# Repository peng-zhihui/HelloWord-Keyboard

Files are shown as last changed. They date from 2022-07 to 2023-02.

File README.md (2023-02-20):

# 【瀚文】HelloWord-Smart Keyboard

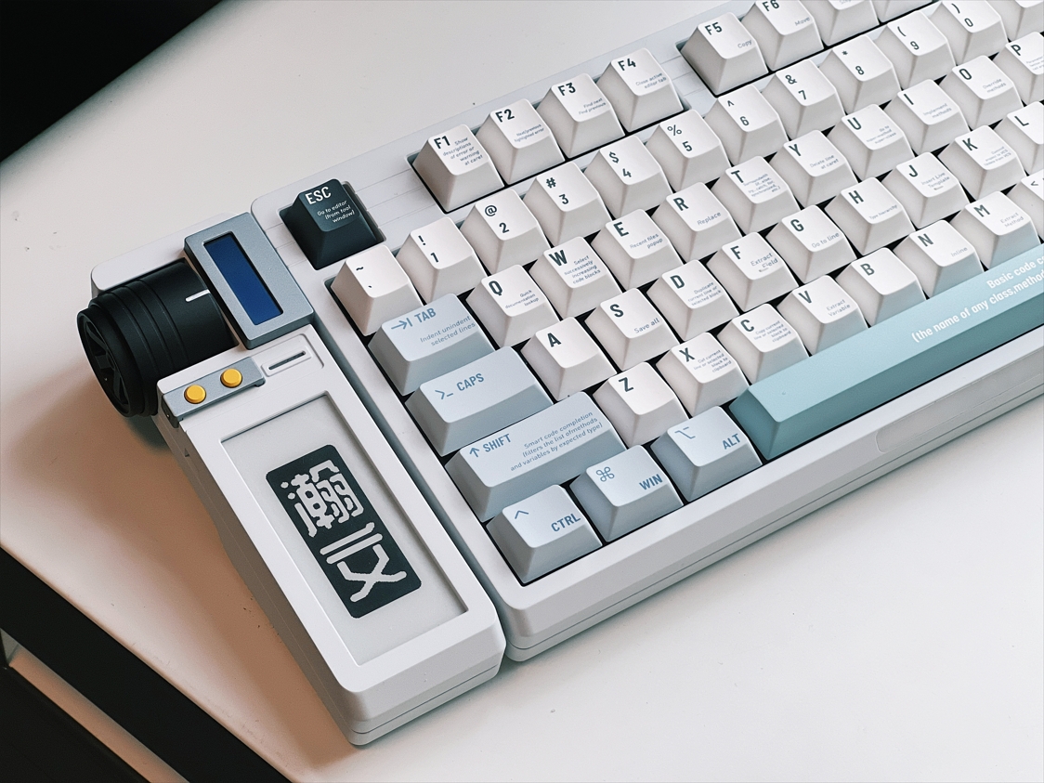
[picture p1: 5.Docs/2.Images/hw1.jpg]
hw1


> `瀚文` 智能键盘是一把我为自己使用需求设计的 **多功能**、**模块化** 机械键盘。
>
> 键盘使用模块化设计，左侧的**多功能场景交互模块**可以替换成各种自定义组件，默认使用的是一个带电子墨水屏以及FOC力反馈旋钮的`Dynamic组件`；键盘使用我自己开发的基于ARM Cortex-M芯片的键盘固件以及模块固件；键盘本体使用移位寄存器方式实现优化的按键扫描电路；模块以及键盘本体可以单独使用，也可以通过串口协议进行相互通信和调用。
>
> **本仓库开源的资料内容包括：**
>
> * 瀚文本体硬件设计的10块PCB设计源文件，提供立创EDA专业版的文件格式
> * 外壳设计结构文件
> * 键盘本体的固件源码（已相对完善）
> * Dynamic组件的固件源码（已完成框架，更多APP扩展WIP）
> * 键盘二次开发SDK（开发中）
>
> **键盘功能演示可以参考：**
>
> * [【自制】我做了一把 模 块 化 机 械 键 盘 !【软核】_哔哩哔哩_bilibili](https://www.bilibili.com/video/BV19V4y1J7Hx)
>
> * [I Made A Customized Modular Keyboard ! - YouTube](https://www.youtube.com/watch?v=mGShD9ZER1c)

**注意：Issues里面是讨论项目开发相关话题的，不要在里面发无意义的消息，不然watch了仓库的人都会收到通知邮件会给别人造成困扰的！！！灌水可以在仓库的Discuss里讨论！**

---

## 1. 项目说明

### 1.0 更新说明：
**23.2.20更新**
* 修改`CUSTOM_HID_EPOUT_ADDR = 2`，HID_RxCpltCallback位置变更到CUSTOM_HID_OutEvent_FS中（原来的位置可能导致while循环内无法发送report）。

  > * main里面增加了RGB控制相关代码，可以通过HID协议发送数据包来控制键盘RGB效果
  > * 已对接SignalRGB，Software中添加SignalRGB插件
  > * report包大小33字节，前三个字节依次为reportid(本项目为2)、控制命令（0xAC（上位机控制），0xBD（关闭上位机控制），report包次序（一个包最多传10个RGB值，需要多个包拼接，从0计算）；后30字节为RGB值。

**22.8.31更新：**

* 添加`Test-Dynamic-fw.bin`测试固件，烧录到模块之后可以体验各种不同力反馈的滚轮效果。

  > * 注意测试版固件会在每次上电之后校准电机，如果校准失败需要重新上电（未来正式使用的时候校准只需要一次就行了）;
  > * 模块上两个按钮可以切换不同模式;
  > * 硬件上有一个地方需要注意的地方是模块的fpc线一定要选短一点的，不然电阻太大会影响压降，同时需要先自己确认一下编码器是正常工作的（可以用Debug查看编码器数据）。

**22.8.22更新：**

* 添加STEP格式的3D模型文件，全套包括定位板的模型都发出来了.

**22.8.20更新：**

* PCB工程更新，见仓库的工程链接，所有元器件能在立创直接下单的都改成了对应的封装，方便大家配置BOM.

**22.8.13更新：**

* 新打样的PCB已经收到，但是由于何同学这周发视频，为了避免带来不必要的压力，所以决定错峰下周六再把PCB工程更新（doge）.

**22.7.31更新：**

* 添加键盘硬件所有设计原理图文件（电路还有些bug没修复，如视频里的飞线，会晚些等新版PCB打样收到验证没问题后更新）
* 添加键盘固件源代码
* 添加Dynamic组件源代码

### 1.1 项目文件说明：

#### 1.1.1 Hardware

Hardware文件夹内是瀚文键盘里面用到的所有电路的原理图和PCB文件，目前提供的是[立创EDA专业版](https://oshwhub.com/pengzhihui/b11afae464c54a3e8d0f77e1f92dc7b7)格式的源文件以及Gerber格式的光绘文件用于提供给厂家进行直接加工。

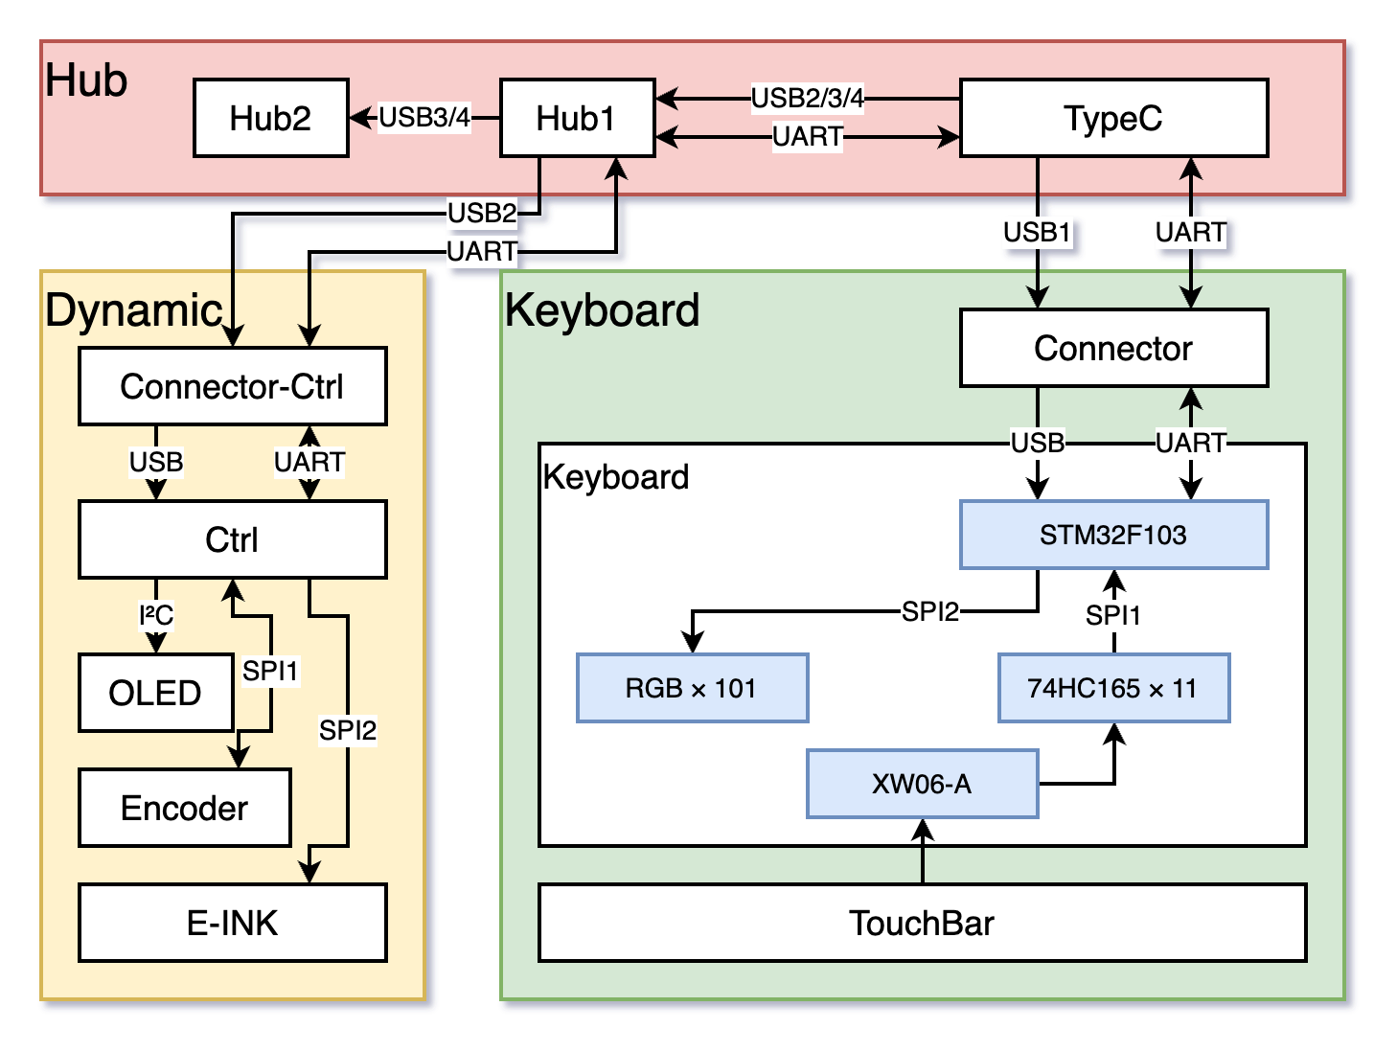
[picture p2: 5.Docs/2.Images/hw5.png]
hw0


一共有如下几块板子：

- **HelloWord-Keyboard**：主键盘的PCB，控制器为STM32F103，可以配合底座单独使用，提供常规按键输入功能，带全按键独立RGB灯。
- **HelloWord-Ctrl**：左侧Dynamic组件的PCB，控制器为STM32F405，可以配合底座单独使用，提供FOC力反馈旋钮、电子墨水屏显示、OLED显示、RGB灯等功能。
- **HelloWord-Connector**：主键盘用于连接底座的触点PCB，通过FFC排线与键盘PCB连接。
- **HelloWord-Connector-Ctrl**：Dynamic组件用于连接底座的触点PCB，通过FFC排线与Dynamic组件PCB连接。
- **HelloWord-Encoder**：磁编码器PCB，用于对无刷电机进行位置反馈，需要配合一个径向充磁的永磁铁工作。
- **HelloWord-Hub1**：底座上扩展出的两个额外USB-A接口转接PCB，通过FFC排线和TypeC接口板连接。
- **HelloWord-Hub2**：底座上扩展出的两个额外USB-A接口的母座PCB，预留的是USB3.0母座和引脚，但是目前只使用到了2.0接口，未来可以升级到USB3.0的HUB。
- **HelloWord-TypeC**：底座上用于连接电脑的TypeC接口PCB，板载了电源充电管理芯片，以及USB-HUB芯片，通过FFC排线连接其余模块。
- **HelloWord-OLED**：Dynamic组件上OLED屏幕的最小驱动电路以及转接板。
- **HelloWord-TouchBar**：可选的电容触摸条模块PCB，使用6按键电容触摸芯片组成一个线性感应阵列，通过FFC排线和主键盘PCB连接。

#### 1.1.2 Firmware

Firmware中提供了上面所有板子的固件源码，以及**预编译好的bin固件**可以直接烧录，主要包含以下两个工程：

* **HelloWord-Keyboard-fw**：主键盘的固件，主要实现了基于硬件SPI和移位寄存器的高速按键扫描、基于硬件SPI&DMA的总线式RGB灯控制、HID高速设备键盘枚举&报文协议实现、非易失存储配置、多层按键映射等功能。
* **HelloWord-Dynamic-fw：**Dynamic组件的固件，主要实现了基于FOC的电机控制代码、可配置触感封装类、电子墨水屏驱动、OLED驱动、USB全速复合设备枚举和通信协议、RGB灯控制等功能。

工程都是基于STM32HAL实现的，所以提供了对应的`.ioc`文件，可以自行用STM32CubeMX打开，生成对应的keil或者STM32IDE工程文件。当让也可以像我一样，用CLion或者STM32CubeIDE进行编译和下载。

`_Release`文件夹里是预编译好的bin文件，可以用**ST-Link Utillity**或者STM32CubeProgrammer之类的软件直接下载到芯片。

关于固件的实现细节后文有讲解。

> 把CLion变成STM32的IDE的方法参考我之前发的一篇教程：[配置CLion用于STM32开发【优雅の嵌入式开发】](https://zhuanlan.zhihu.com/p/145801160) 。

#### 1.1.3 Software

Software中提供了一些用于和键盘交互的电脑端上位机软件，包括视频里演示的傻瓜化修改墨水屏图片的上位机软件，以及后续会逐步补充用于**修改键位的图形化软件**给**模块添加APP**的应用商店软件，这些还在开发中。

#### 1.1.4 Tools

Tools主要是提供一些三方的工具软件，比如**STM32 ST-LINK Utility** 、用于安装驱动的**zadig**等等。

#### 1.1.5 3D Model

文件夹里是键盘用到的所有结构件的3D模型文件，可以用于3D打印。

#### 1.1.6 Docs

相关的参考文件，包括芯片的Datasheet等。

## 2. 硬件架构说明

**关于结构设计？**

瀚文的结构包括三大部分：**扩展坞底座**、**键盘输入模块**和**可替换的多功能交互模块**，键盘输入模块和可替换的多功能交互模块通过若干接触式触点连接在所述扩展坞底座顶部：

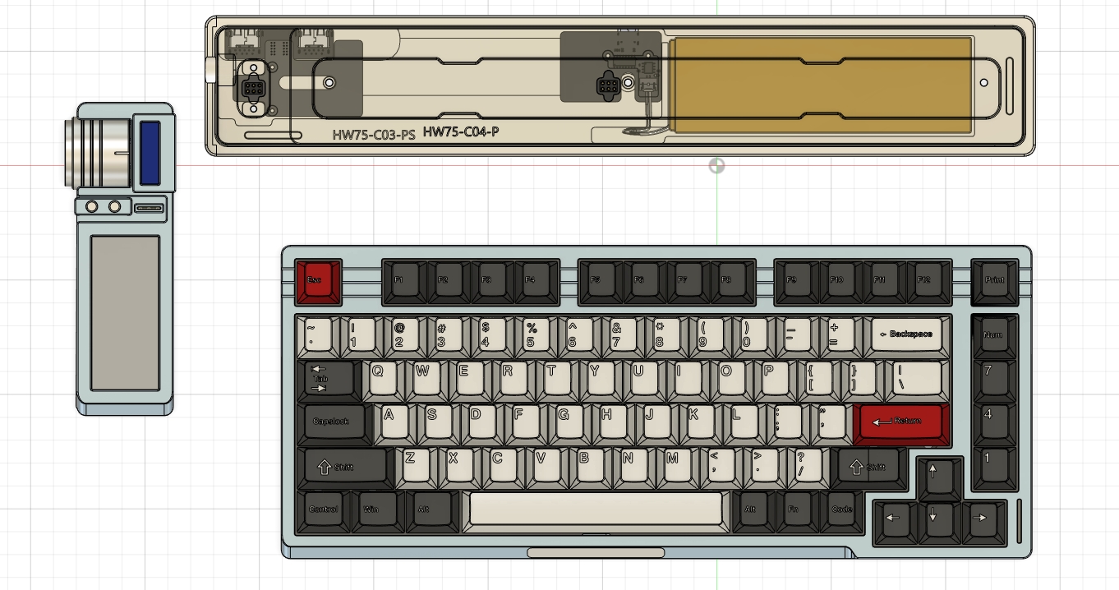
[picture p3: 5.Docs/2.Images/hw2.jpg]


而键盘本体也是一个标准的客制化键盘层叠结构设计，包含减震棉、PCBA、定位板、轴下垫等：

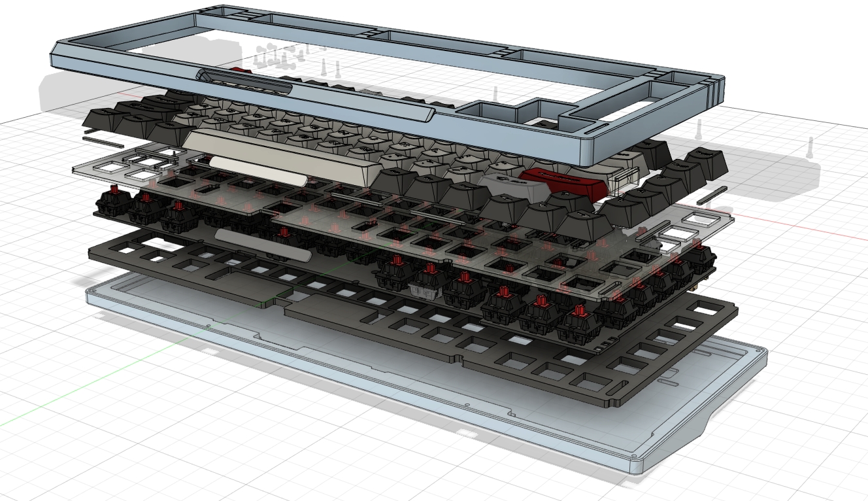
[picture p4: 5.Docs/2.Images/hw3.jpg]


键盘的结构设计主要是Xikii根据S98修改而来，为75键布局，有其他布局需要的同学可以自行修改PCB和固件适配。

> 关于视频中展示的结构件，由于是Xikii的方案所以我也不好擅自把源文件放出，而且原始版本结构是用于CNC机加工的，成本会比较高。
>
> 所以我也让Xikii帮忙设计一套简化版可用于3D的结构件，并开源出来放到仓库。

**关于芯片选型？**

- 键盘主控选用的芯片是STM32F103CBT6，实际上C8T6也可以，不过考虑到未来固件功能的扩展性，Flash大一倍的CBT6性价比更高。这块由于我固件基本都是使用HAL库实现的，因此实际上也可以把主控替换成STM32系列的任何一款芯片，需要支芯片有2个SPI硬件接口分别用于按键扫描以及RGB灯驱动，以及一个全速USB接口即可。
- Dynamic组件主控的STM32F4，这个是因为我手边这款芯片比较多，理论上可以替换为性价比更高的F1系列的，只要芯片具备一个高级定时器用于PWM生成、2个硬件SPI接口用于编码器和电子墨水屏通信、一个I2C接口用于OLED驱动，以及一个全速USB接口即可。
- 电机的磁编码器芯片我是使用AS5047P，也是一款很常用性能很好的磁编码芯片，不过成本略高，我只是因为手边有所以选了这款，也是可以修改为其他更便宜的型号的比如MT6816等，当然也需要修改固件驱动代码。
- 按键扫描用的移位寄存器使用的74HC165，国产芯片零售的话大概0.5元一片，一片可以驱动8个按键，按照你自己需要的按键数目修改串联的寄存器芯片即可。进口的165比如TI原装的要比国产贵一些，性能也会稍微好点，不过由于本项目中按键扫描频率4MHz已经完全够用了，因此哪怕国产的16MHz芯片也绰绰有余了。
- 电容触摸板使用的是一个6通道电容触摸按键芯片XW06A实现的，这个对于PCB感应盘的设计有一定要求，仓库已经提供了设计好的PCB。对于该芯片的读取方式，其实和普通按键没有区别，所以本方案中也是使用74HC165进行扫描读取的。
- 电机FOC驱动电路完全是从我的Ctrl驱动器中移植过来的，使用FD8288Q作为栅极驱动器，无需电流传感器。

**关于烧录方式？**

使用JLink、STLink之类的调试器烧录，我在PCB和外壳上都预留了SWD调试口。对于没有硬件开发经验的同学，我晚点也会放出一个Bootloader，可以直接通过USB口进行固件升级。

**关于电机选型？**

我使用的是一个2204的二手电机，不过这一款电机目前好像不太好买，大家可以选取类似尺寸的无刷电机替换，参数方面需要KV值低一些，最好200左右。电机需要手动在转子上安装一个径向充磁的永磁体用于编码器定位，不同型号的电机需要对FOC参数进行一些调整。

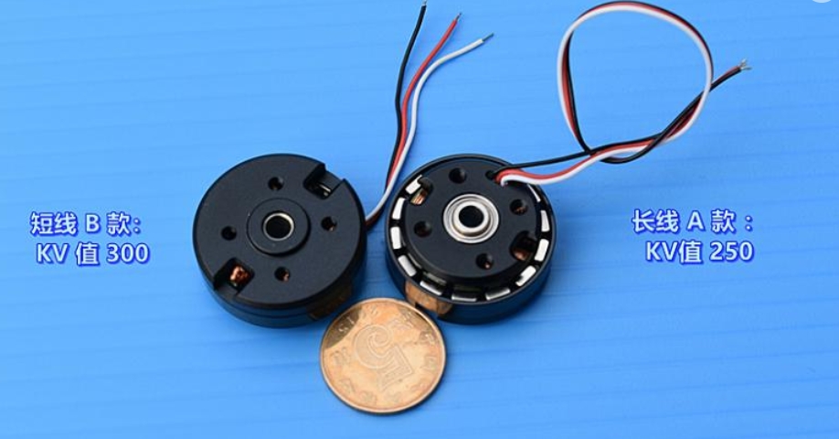
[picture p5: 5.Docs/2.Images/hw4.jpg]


## 3. 软件架构说明

**关于键盘固件的按键映射方式？**

为了充分发挥视频中提到的移位寄存器扫描方案的优势，固件代码中将PCB Layout走线和按键扫描顺序解耦，通过软件进行重映射。也就是说PCB中按键的连接可以是任意的，走完线之后可以在`hw_keyboard.h`文件中的`keyMap[KEYMAP_NUM][IO_NUMBER]`中指定映射方式。

> 这是一个二维数组，代表有`KEYMAP_NUM`层键位映射，每一层有`IO_NUMBER`个按键（也就是你的键盘按键数目）；其中第0层是特殊的，负责映射PCB按键的随机布局到键盘标准按键布局，后续的1、2、3、4...层都是自定义的，负责映射标准按键布局到任意布局。

**举个例子：**

考虑原理图中箭头指的那个按键，这个按键可以在PCB的任意位置，但是我们可以看到，它是从左到右（按74HC165的连接顺序，也即移位扫描顺序）的第10颗，因此它的编号为9（从0开始算）.

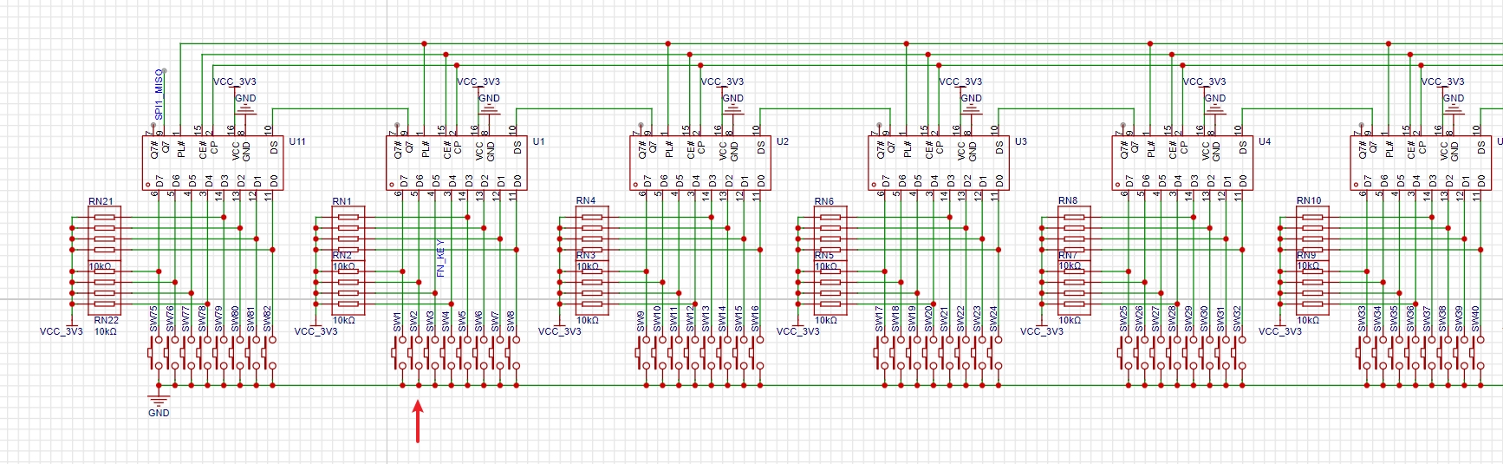
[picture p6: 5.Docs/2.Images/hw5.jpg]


如果我们在实际的PCB板上把它放在了**右边Alt**的位置，那么参考在下图代码**红色框**中的第1层映射（也就是标准布局）中的`RIGHT_ALT`的序号是76，那么在第0层映射的76号变量就填入9（蓝色框）.

这样依次把你PCB上所有按键都填入0层映射，就得到了一个映射好的标准键盘了。后续2、3、4、5...层需要怎么映射就随意修改添加即可，也不需要再使用数字编号，而是可以直接用枚举的按键名称很方便。

> 所以对于想修改键盘配列的人，只需要再原理图上添加或删减几个串联的74HC165，然后PCB随意走线，再将代码中0层映射删减或增加一些数字即可（比如在下面的例子中我的键盘是83键的）；后面几层的修改就以此类推了。

代码中通过`keyboard.Remap`函数来映射不同层，比如`keyboard.Remap(2)`这一句是使用第2层映射。

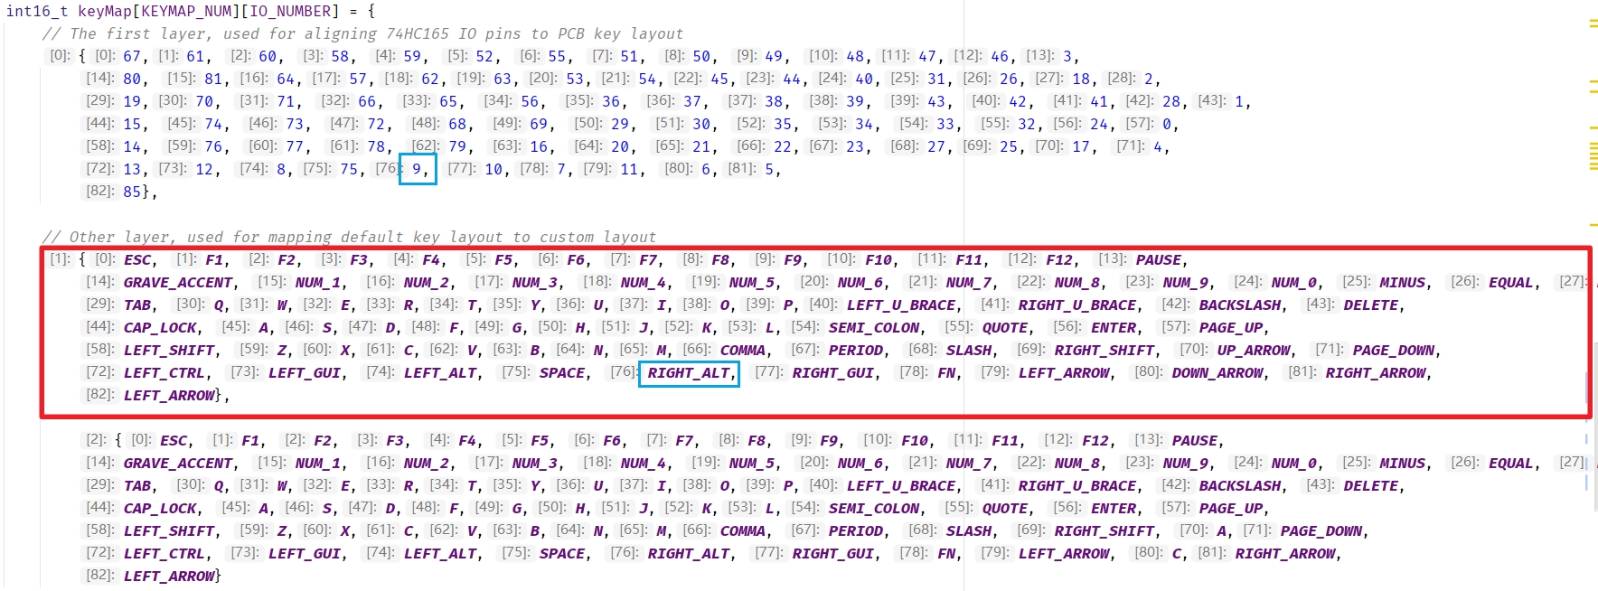
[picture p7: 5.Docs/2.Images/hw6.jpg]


**关于键盘固件的滤波方法？**

固件中使用了每个按键独立的滤波，但是是以一种非常高效的方式来实现的（毕竟1KHz的报文，每个报文期间至少扫描两次按键，意味着每秒钟需要进行 **1000\*2\*[按键数目]** 次数的滤波）。

基本原理很简单，就是按键抖动的原因是按下后会在高低电平之间反复横跳，这个稳定时间一般是几十us（注意是电平稳定时间，不是按键触发时间，后者是由于按键簧片接触时间的不确定性导致的，可能长达数ms）。

在QMK的[qmk_firmware/feature_debounce_type](https://github.com/qmk/qmk_firmware/blob/master/docs/feature_debounce_type.md)文档中描述了其使用的几种滤波方法，分为Eager和Defer、对称和非对称等，

默认是使用**对称延迟全局滤波**，也就是说是对所有按键进行同等的滤波，等所有的按键都稳定了不再变化，再提交扫描数据。

> 与之对应的是激进滤波方法，也就是说一旦检测到按键变化就提交数据，但是在这之后的N毫秒时间内不再响应任何按键（也就避免了把不断抖动的按键提交上去）。这种方法触发延迟低，但是对噪声很敏感，容易误触发。

我在瀚文的固件中使用的是**对称延迟独立滤波**，也就是对每个按键进行两次检测，如果第一次检测到了按键变化，那么相隔N微秒（这个参数可以配置，大于按键典型抖动时间即可）再检测一次，如果两次检测结果一致，那么判断按键被按下，此时可以确保按键发生了变化，且不会重复触发按键，兼顾延迟和稳定性。

这个过程是通过异或运算进行高效处理的，正好按键buffer由于是移位寄存器扫描得到的，本身就是每一位代表一个按键，所以滤波效率非常高，实测效果也挺好的。

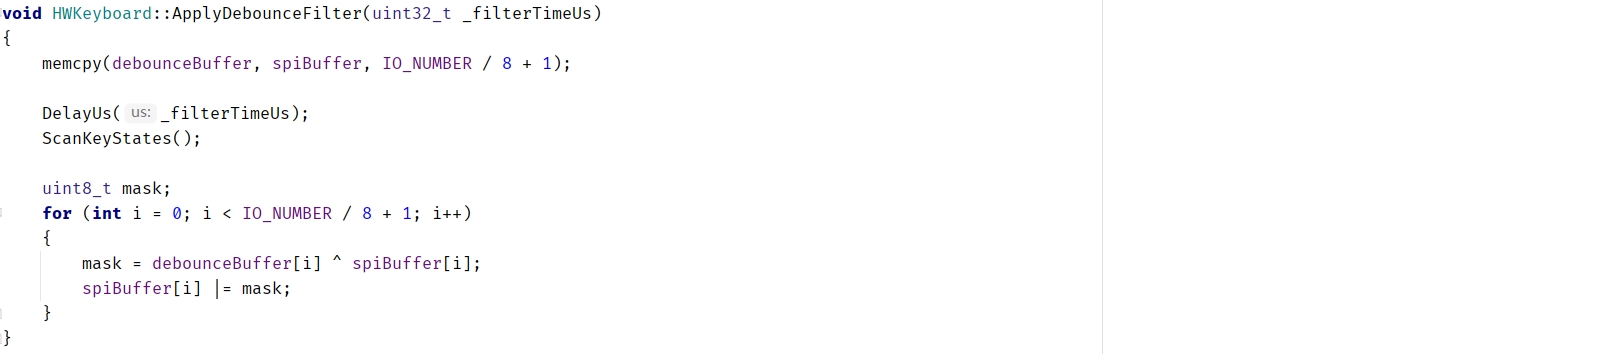
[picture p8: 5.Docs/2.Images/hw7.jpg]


**关于键盘固件的HID描述符？**

这个可以直接参考源码的`usbd_customhid.c`文件，我配置了两个ReportID，ID-0是上报键位扫描数据的（全键无冲），ID-1是预留用于后续跟上位机改键软件通信用的。

**关于RGB的控制？**

代码中使用的是单总线的ws2812b系列灯珠，一根线就可以串联一大堆RGB，而且代码中实现了SPI-DMA模拟时序，得到了超高的刷新率。

目前代码里只写了一个demo灯效（非常简单就是轮询色彩），自己添加额外的灯效的话，通过`keyboard.SetRgbBuffer`函数设置RGB值，然后`SyncLights`把数据发送给LED即可：

```
while (true)
    {
        /*---- This is a demo RGB effect ----*/
        static uint32_t t = 1;
        static bool fadeDir = true;

        fadeDir ? t++ : t--;
        if (t > 250) fadeDir = false;
        else if (t < 1) fadeDir = true;

        for (uint8_t i = 0; i < HWKeyboard::LED_NUMBER; i++)
            keyboard.SetRgbBuffer(i, HWKeyboard::Color_t{(uint8_t) t, 50, 0});
        /*-----------------------------------*/

        // Send RGB buffers to LEDs
        keyboard.SyncLights();
    }
```

## 4. SDK设计 & 二次开发

待补充。

> 感谢以下项目：
>
> [Lexikos/AutoHotkey_L: AutoHotkey - macro-creation and automation-oriented scripting utility for Windows. (github.com)](https://github.com/Lexikos/AutoHotkey_L)
>
> [olikraus/u8g2: U8glib library for monochrome displays, version 2 (github.com)](https://github.com/olikraus/u8g2)
>
> [simplefoc/Arduino FOC for BLDC  (github.com)](https://github.com/simplefoc/Arduino-FOC)
>
> [zhongyang219/TrafficMonitor: 这是一个用于显示当前网速、CPU及内存利用率的桌面悬浮窗软件，并支持任务栏显示，支持更换皮肤。 (github.com)](https://github.com/zhongyang219/TrafficMonitor)

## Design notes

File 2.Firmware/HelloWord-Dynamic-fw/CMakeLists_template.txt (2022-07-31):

#THIS FILE IS AUTO GENERATED FROM THE TEMPLATE! DO NOT CHANGE!
set(CMAKE_SYSTEM_NAME Generic)
set(CMAKE_SYSTEM_VERSION 1)
cmake_minimum_required(VERSION 3.19)

# specify cross compilers and tools
set(CMAKE_C_COMPILER arm-none-eabi-gcc)
set(CMAKE_CXX_COMPILER arm-none-eabi-g++)
set(CMAKE_ASM_COMPILER arm-none-eabi-gcc)
set(CMAKE_AR arm-none-eabi-ar)
set(CMAKE_OBJCOPY arm-none-eabi-objcopy)
set(CMAKE_OBJDUMP arm-none-eabi-objdump)
set(SIZE arm-none-eabi-size)
set(CMAKE_TRY_COMPILE_TARGET_TYPE STATIC_LIBRARY)

# project settings
project(HelloWord-Dynamic-fw C CXX ASM)
set(CMAKE_CXX_STANDARD 17)
set(CMAKE_C_STANDARD 11)

# for use printf & scanf with float
set(COMMON_FLAGS "-specs=nosys.specs -specs=nano.specs -u _printf_float -u _scanf_float")

#Uncomment for hardware floating point
add_compile_definitions(ARM_MATH_CM4;ARM_MATH_MATRIX_CHECK;ARM_MATH_ROUNDING)
add_compile_options(-mfloat-abi=hard -mfpu=fpv4-sp-d16)
add_link_options(-mfloat-abi=hard -mfpu=fpv4-sp-d16)

#Uncomment for software floating point
#add_compile_options(-mfloat-abi=soft)

add_compile_options(-mcpu=cortex-m4 -mthumb -mthumb-interwork)
add_compile_options(-ffunction-sections -fdata-sections -fno-common -fmessage-length=0)
set(CMAKE_CXX_FLAGS "${CMAKE_CXX_FLAGS} -fno-exceptions -fno-rtti")

# uncomment to mitigate c++17 absolute addresses warnings
#set(CMAKE_CXX_FLAGS "${CMAKE_CXX_FLAGS} -Wno-register")

if ("${CMAKE_BUILD_TYPE}" STREQUAL "Release")
    message(STATUS "Maximum optimization for speed")
    add_compile_options(-Ofast)
elseif ("${CMAKE_BUILD_TYPE}" STREQUAL "RelWithDebInfo")
    message(STATUS "Maximum optimization for speed, debug info included")
    add_compile_options(-Ofast -g)
elseif ("${CMAKE_BUILD_TYPE}" STREQUAL "MinSizeRel")
    message(STATUS "Maximum optimization for size")
    add_compile_options(-Os)
else ()
    message(STATUS "Minimal optimization, debug info included")
    add_compile_options(-Og -g)
endif ()

include_directories(
        ./
        Core/Inc
        Drivers/STM32F4xx_HAL_Driver/Inc
        Drivers/STM32F4xx_HAL_Driver/Inc/Legacy
        Drivers/CMSIS/Device/ST/STM32F4xx/Include
        Drivers/CMSIS/Include
        Middlewares/Third_Party/FreeRTOS/Source/include
        Middlewares/Third_Party/FreeRTOS/Source/CMSIS_RTOS_V2
        Middlewares/Third_Party/FreeRTOS/Source/portable/GCC/ARM_CM4F
        Middlewares/ST/STM32_USB_Device_Library/Core/Inc
        Middlewares/ST/STM32_USB_Device_Library/Class/CDC/Inc
        USB_DEVICE/App
        USB_DEVICE/Target
        BSP/fibre/cpp/include
        BSP/u8g2
        BSP/u8g2/cpp
        BSP/uvector
        BSP/eink
        Platform/Utils
        UserApp
)

add_definitions(-DUSE_HAL_DRIVER -DSTM32F4 -DSTM32F4xx -DSTM32F405xx -DconfigAPPLICATION_ALLOCATED_HEAP)

file(GLOB_RECURSE SOURCES
        "startup/*.*"
        "Drivers/*.*"
        "Core/*.*"
        "BSP/*.*"
        "Middlewares/*.*"
        "USB_DEVICE/*.*"
        "Ctrl/*.*"
        "Platform/*.*"
        "UserApp/*.*"
        )

set(LINKER_SCRIPT ${CMAKE_SOURCE_DIR}/STM32F405RGTx_FLASH.ld)

add_link_options(-Wl,-gc-sections,--print-memory-usage,-Map=${PROJECT_BINARY_DIR}/${PROJECT_NAME}.map)
add_link_options(-mcpu=cortex-m4 -mthumb -mthumb-interwork)
add_link_options(-T ${LINKER_SCRIPT})

link_directories("Drivers/CMSIS/Lib")
link_libraries("arm_cortexM4lf_math.a")

add_executable(${PROJECT_NAME}.elf ${SOURCES} ${LINKER_SCRIPT})

set(HEX_FILE ${PROJECT_BINARY_DIR}/${PROJECT_NAME}.hex)
set(BIN_FILE ${PROJECT_BINARY_DIR}/${PROJECT_NAME}.bin)

add_custom_command(TARGET ${PROJECT_NAME}.elf POST_BUILD
        COMMAND ${CMAKE_OBJCOPY} -Oihex $<TARGET_FILE:${PROJECT_NAME}.elf> ${HEX_FILE}
        COMMAND ${CMAKE_OBJCOPY} -Obinary $<TARGET_FILE:${PROJECT_NAME}.elf> ${BIN_FILE}
        COMMENT "Building ${HEX_FILE}
Building ${BIN_FILE}")

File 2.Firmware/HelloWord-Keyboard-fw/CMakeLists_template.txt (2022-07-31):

#THIS FILE IS AUTO GENERATED FROM THE TEMPLATE! DO NOT CHANGE!
set(CMAKE_SYSTEM_NAME Generic)
set(CMAKE_SYSTEM_VERSION 1)
cmake_minimum_required(VERSION 3.22)

# specify cross-compilers and tools
set(CMAKE_C_COMPILER arm-none-eabi-gcc)
set(CMAKE_CXX_COMPILER arm-none-eabi-g++)
set(CMAKE_ASM_COMPILER  arm-none-eabi-gcc)
set(CMAKE_AR arm-none-eabi-ar)
set(CMAKE_OBJCOPY arm-none-eabi-objcopy)
set(CMAKE_OBJDUMP arm-none-eabi-objdump)
set(SIZE arm-none-eabi-size)
set(CMAKE_TRY_COMPILE_TARGET_TYPE STATIC_LIBRARY)

# project settings
project(HelloWord-Keyboard-fw C CXX ASM)
set(CMAKE_CXX_STANDARD 17)
set(CMAKE_C_STANDARD 11)
set(CMAKE_CXX_FLAGS "${CMAKE_CXX_FLAGS} -fno-exceptions -fno-rtti")

#Uncomment for hardware floating point
#add_compile_definitions(ARM_MATH_CM4;ARM_MATH_MATRIX_CHECK;ARM_MATH_ROUNDING)
#add_compile_options(-mfloat-abi=hard -mfpu=fpv4-sp-d16)
#add_link_options(-mfloat-abi=hard -mfpu=fpv4-sp-d16)

#Uncomment for software floating point
#add_compile_options(-mfloat-abi=soft)

add_compile_options(-mcpu=cortex-m3 -mthumb -mthumb-interwork)
add_compile_options(-ffunction-sections -fdata-sections -fno-common -fmessage-length=0)

# uncomment to mitigate c++17 absolute addresses warnings
#set(CMAKE_CXX_FLAGS "${CMAKE_CXX_FLAGS} -Wno-register")

# Enable assembler files preprocessing
add_compile_options($<$<COMPILE_LANGUAGE:ASM>:-x$<SEMICOLON>assembler-with-cpp>)

if ("${CMAKE_BUILD_TYPE}" STREQUAL "Release")
    message(STATUS "Maximum optimization for speed")
    add_compile_options(-Ofast)
elseif ("${CMAKE_BUILD_TYPE}" STREQUAL "RelWithDebInfo")
    message(STATUS "Maximum optimization for speed, debug info included")
    add_compile_options(-Ofast -g)
elseif ("${CMAKE_BUILD_TYPE}" STREQUAL "MinSizeRel")
    message(STATUS "Maximum optimization for size")
    add_compile_options(-Os)
else ()
    message(STATUS "Minimal optimization, debug info included")
    add_compile_options(-Og -g)
endif ()

include_directories(
        ./
        USB_DEVICE/App
        USB_DEVICE/Target
        Core/Inc
        Drivers/STM32F1xx_HAL_Driver/Inc
        Drivers/STM32F1xx_HAL_Driver/Inc/Legacy
        Middlewares/ST/STM32_USB_Device_Library/Core/Inc
        Middlewares/ST/STM32_USB_Device_Library/Class/CustomHID/Inc
        Drivers/CMSIS/Device/ST/STM32F1xx/Include
        Drivers/CMSIS/Include
        UserApp
)

add_definitions(-DUSE_HAL_DRIVER -DSTM32F103xB)

file(GLOB_RECURSE SOURCES
        startup/*.*
        Middlewares/*.*
        Drivers/*.*
        USB_DEVICE/*.*
        Core/*.*
        HelloWord/*.*
        UserApp/*.*
        )

set(LINKER_SCRIPT ${CMAKE_SOURCE_DIR}/STM32F103CBTx_FLASH.ld)

add_link_options(-Wl,-gc-sections,--print-memory-usage,-Map=${PROJECT_BINARY_DIR}/${PROJECT_NAME}.map)
add_link_options(-mcpu=cortex-m3 -mthumb -mthumb-interwork)
add_link_options(-T ${LINKER_SCRIPT})

add_executable(${PROJECT_NAME}.elf ${SOURCES} ${LINKER_SCRIPT})

set(HEX_FILE ${PROJECT_BINARY_DIR}/${PROJECT_NAME}.hex)
set(BIN_FILE ${PROJECT_BINARY_DIR}/${PROJECT_NAME}.bin)

add_custom_command(TARGET ${PROJECT_NAME}.elf POST_BUILD
        COMMAND ${CMAKE_OBJCOPY} -Oihex $<TARGET_FILE:${PROJECT_NAME}.elf> ${HEX_FILE}
        COMMAND ${CMAKE_OBJCOPY} -Obinary $<TARGET_FILE:${PROJECT_NAME}.elf> ${BIN_FILE}
        COMMENT "Building ${HEX_FILE}
Building ${BIN_FILE}")

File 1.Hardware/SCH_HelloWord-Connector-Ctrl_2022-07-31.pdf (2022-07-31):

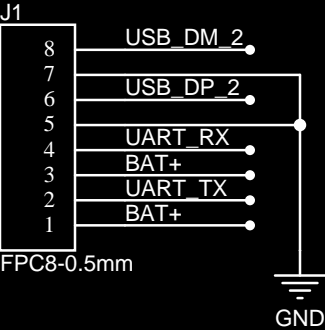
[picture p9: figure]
FPC8-0.5mm; GND; USB_DM_2; USB_DP_2; UART_RX; UART_TX; BAT+

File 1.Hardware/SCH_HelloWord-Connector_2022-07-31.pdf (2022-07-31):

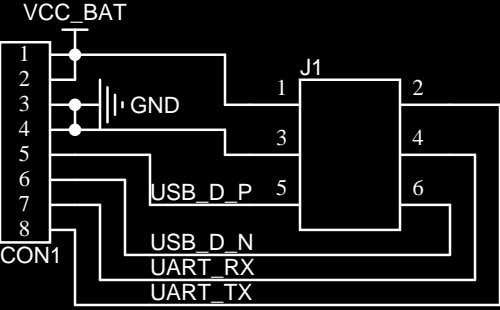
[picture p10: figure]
CON1; VCC_BAT; GND; USB_D_P; USB_D_N UART_RX UART_TX

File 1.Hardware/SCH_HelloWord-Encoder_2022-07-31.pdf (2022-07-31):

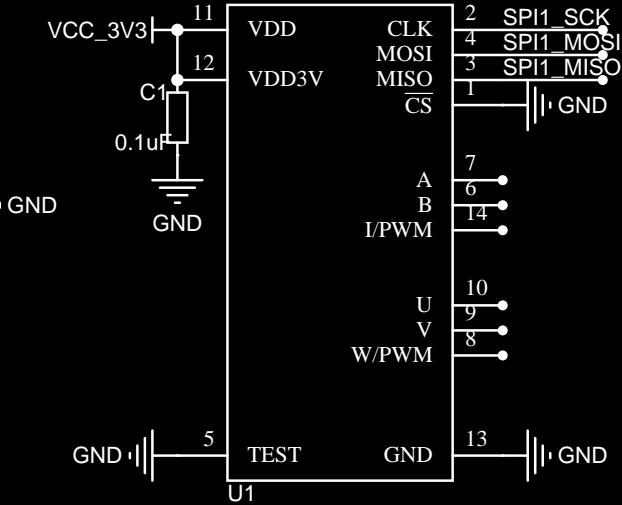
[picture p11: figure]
VDD; VDD3V; CLK; I/PWM; MISO; MOSI; TEST; W/PWM; GND; VCC_3V3; SPI1_SCK SPI1_MOSI SPI1_MISO
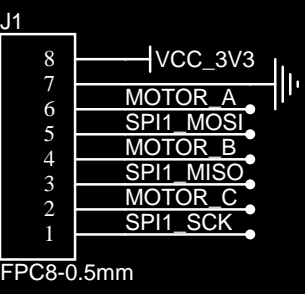
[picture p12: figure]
FPC8-0.5mm; VCC_3V3 MOTOR_A; MOTOR_B; MOTOR_C SPI1_SCK; SPI1_MOSI; SPI1_MISO

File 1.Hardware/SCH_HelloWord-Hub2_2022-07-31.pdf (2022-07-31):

### GND

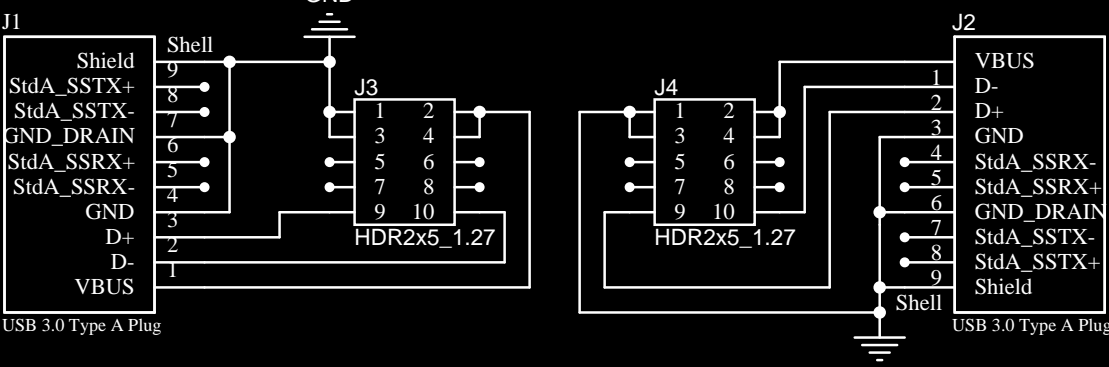
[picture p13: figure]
HDR2x5_1.27; VBUS; GND; StdA_SSRX-; StdA_SSRX+; GND_DRAIN; StdA_SSTX-; StdA_SSTX+; Shield; Shell; USB 3.0 Type A Plug; GND 4; StdA_SSRX- 5; StdA_SSRX+ 6; GND_DRAIN 7; StdA_SSTX- 8; StdA_SSTX+ 9

### GND

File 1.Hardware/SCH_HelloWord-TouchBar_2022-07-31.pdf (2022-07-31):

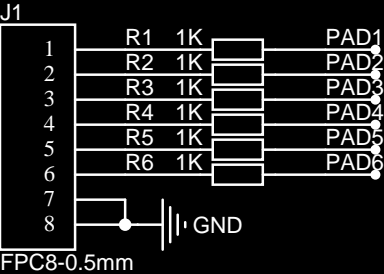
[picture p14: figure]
GND; FPC8-0.5mm; PAD1 PAD2 PAD3 PAD4 PAD5 PAD6

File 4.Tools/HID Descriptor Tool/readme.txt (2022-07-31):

Descriptor Tool, Version 2.4

The major changes to 2.4 are:

1) Fixed monitor enumerated values. Needed to have usage 1 display "Enum 0".
   Added REPEATING0 option to .UPG files to fix this.

2) Added a title bar to the Usage Page Dialog box.

3) Fixed incorrect Extended Usages during inital insertion.

4) Added concatonation of Ordinal Instance value to Usages in collection
   immediately following Ordinal declaration.

5) Fixed display of Extended Usages when No Data option is selected.

6) Added support for Vendor Defined Usage Tables.

The major changes to Version 2.3 are:

1) added sizable window

The major changes to 2.0 are:

1) Incorporated the HID syntax checker from HIDview.

2) The Usage Pages are all ASCII files that can be modified by the user.

3) Extended Usages are supported.

4) Added cut and paste.

5) Report Descriptors files can be saved as .HID, .TXT, .INC, and .H. Only .HID can be read. 

6) Included examples from the HID spec. and the Usage Table document.

7) Fixed numerous bugs.

/************************************************************************
Instructions:

DT.INI must reside in the same directory as DT.EXE.

Usage pages can be added or modified. To add a Usage Page create a text
.UPG file as described below then add an Usage Page (UPn) entry to DT.INI.

NOTE: When saving a file in a format other than .HID be sure to
change the extension otherwise the .HID file will be overwritten.

****************************     WARNING      ***************************
The usages pages (.UPG files) from the 9.0 Release Candidate USB HID Usage
Tables document are included here. These pages are included for convienence
and may change in the final release of the document.
****************************     WARNING      ***************************

/************************************************************************
HID Spec issues:

1) Vendor defined Collection IDs are not supported by DT.

2) Extended Usages are 32-bit usages where the high order 16-bits are the
Usage Page ID and the low order 16-bits are the Usage ID. These are useful
when usages from different Usage Pages are required for the same Main Item.
Memphis supports extended usages. Extended Usages are not defined in the
HID 1.0 Specification.

3) Extended usage values for Usage Minimum and Maximum (32 bit parameters)
are also supported by DT. Memphis supports this too.

4) Memphis has the following restrictions on delimiters:
 - Do not use delimiters for usages associated with top level (application)
       collections.
 - Only Usages are supported in delimiters. Usage Min, Usage Max, Designators
       and Strings are NOT allowed in a delimited set.
 - Delimiters are not allowed when defining usages associated with an Array.

5) The checker (Parse Descriptor) does not support:
 -- Push and Pop - False errors will be reported due to state variables that
are not saved and restored.

 -- Extended Usages - The checker will report extended usages as "undefined"
because it does not break the 32-bit value into Usage and Usage Page.

Report problems to: steve_mcgowan@ccm.jf.intel.com

/************************************************************************
File format definitions:

/************************************************************************
.INI format

[UsagePages]
Count=<total number of usage pages declared>
UP0=<Usage Page ID>,<Usage Page Name>,<.UPG File Name>
UP1=...
...
UP<Count - 1>=...

  UPn, where n increments from 0 to the number of pages declared - 1

Notes:
  The .INI file must be in the same directory as DT.EXE.

  The Usage Page ID is in decimal.

  The Usage Page Name must be identical to that found in the .UPG file.

  The .UPG File Name can include a path.

*************************************************************************
.UPG format

There are 2 types of .UPG files: NORMAL and REPEATING.

NORMAL .UPG files

<Usage Page Name>
<.UPG File Type Flag: NORMAL>
<Usage ID><tab ('\t')><Usage Name> or
; Comment if ';' is first character of a line (ignored) or
<Usage ID-Usage ID><tab><Reserved of reserved> (ignored)

	Notes:
	The Usage Page Name must be identical to the Usage Page Name referred
	to in the .INI file to be recognized as a .UPG file.

	No blank lines can be in the file.

    The Usage ID is in hexidecimal with NO "0x" notation preceeding it
	or "h" following it.

	There are three forms that can follow the File Type Flag:
		1) The Usage ID, followed by a tab character, followed by the
		Usage Name Spaces are allowed in Usage names.
		2) Any line with a semi-colon as the first character is
		considered a comment and ignored.
		3) Any line that has  "Reserved" of "reserved" as the
		Usage Name will be considered a comment and ignored.
		4) Comments are only allowed after the UPG File Type Flag.

  Example:

Generic Desktop
NORMAL
00	Undefined
01	Pointer
02	Mouse
03	Reserved
04	Joystick
05	Game Pad
06	Keyboard
07	Keypad
08-2F	Reserved
30	X
...
81	System Power
82	System Sleep
83-FFFF	Reserved

REPEATING .UPG files

<Usage Page Name>
<.UPG File Type Flag: REPEATING>
00<tab ('\t')><first Usage Name>
01<tab ('\t')><repeated Usage Name>
; Comment if ';' is first character of a line (ignored)

	Notes:
	The Usage Page Name must be identical to the Usage Page Name referred
	to in the .INI file to be recognized as a .UPG file.

	No blank lines can be in the file.

	Only 2 usages are declared. The Usage Name of the first entry (00)
	will be used for the first usage and the Usage Name of the second
	entry will be repeated followed by <space><Usage ID>.

	There are three forms that can follow the File Type Flag:
		1) The Usage ID, followed by a tab character, followed by the
		Usage Name Spaces are allowed in Usage names.
		2) Any line with a semi-colon as the first character is
		considered a comment and ignored.
		3) Any line that has  "Reserved" of "reserved" as the
		Usage Name will be considered a comment and ignored.
		4) Comments are only allowed after the UPG File Type Flag.

  Example:

Button
REPEATING
00	Unused
01	Button

  Results in the usages:

Unused
Button 1
Button 2
Button 3
...

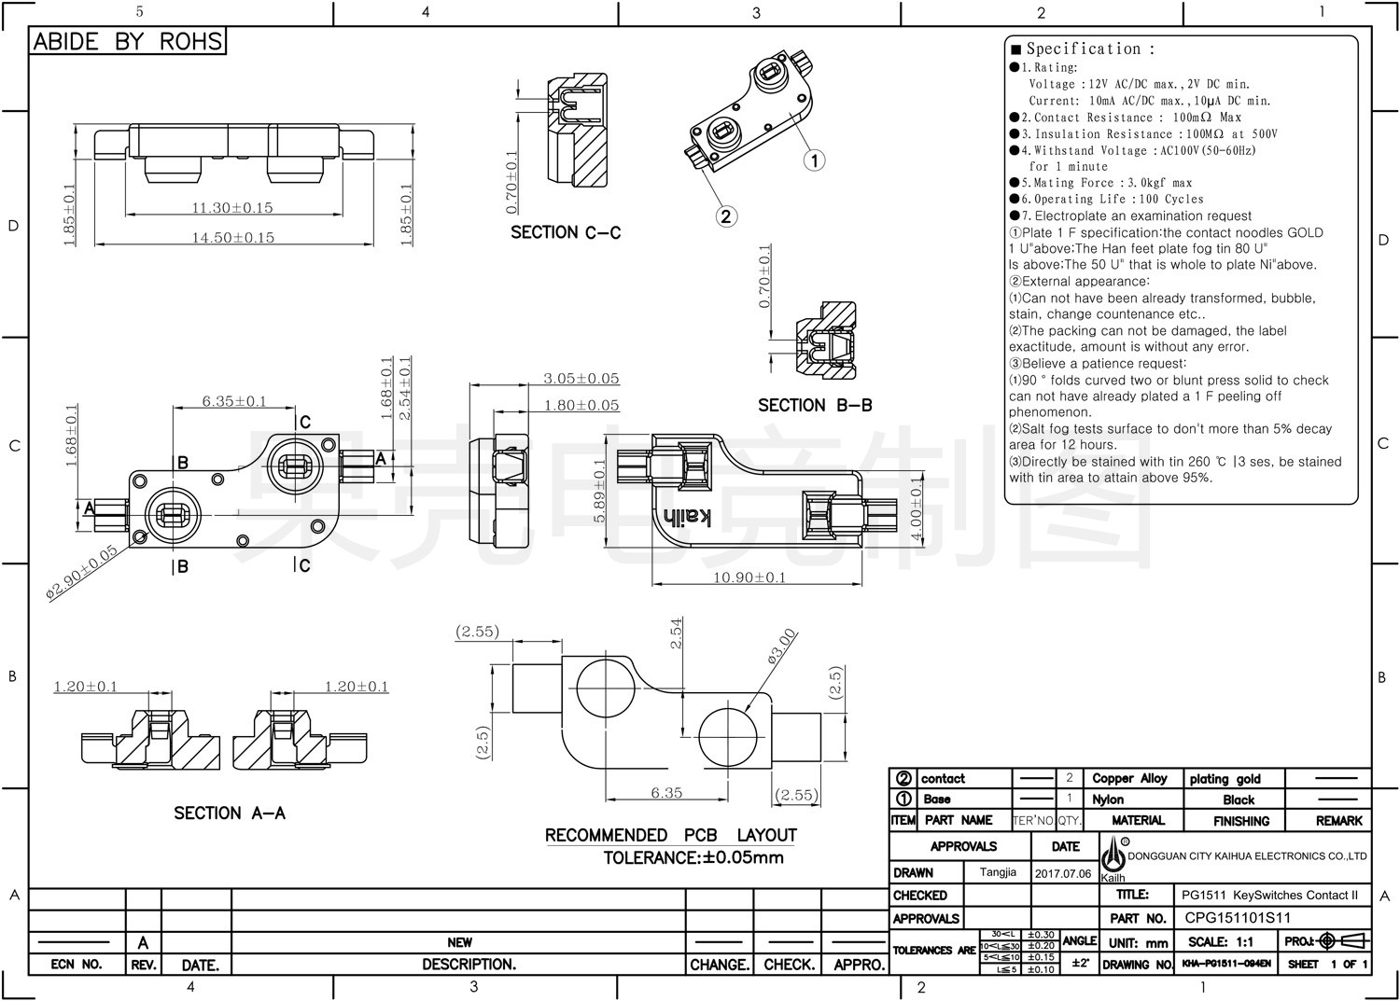
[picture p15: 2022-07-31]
5.Docs/1.Datasheet/凯华热拔插键轴座.jpg

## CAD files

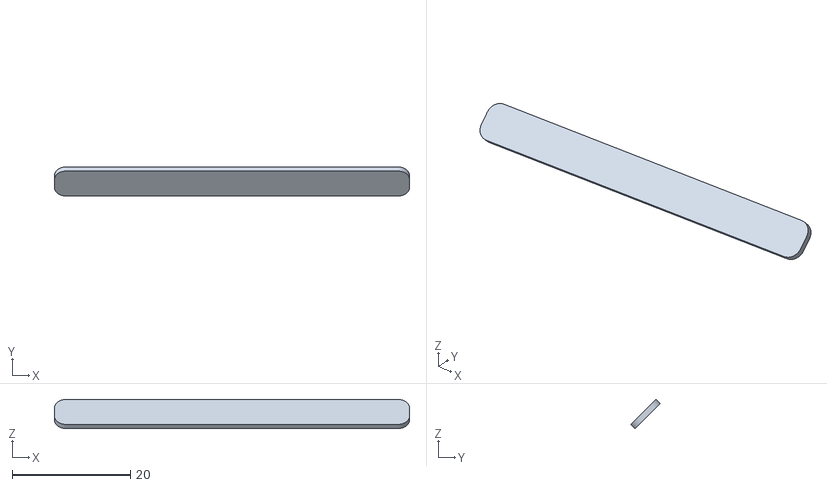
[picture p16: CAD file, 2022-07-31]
5.3D Model/瀚文基础版/05触摸条盖板.stl
60.0 x 4.95 x 4.95

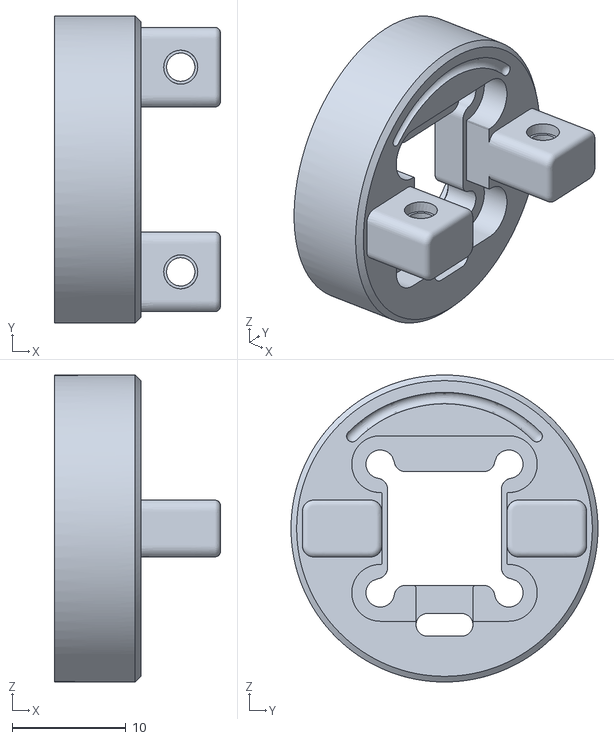
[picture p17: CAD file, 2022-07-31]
5.3D Model/瀚文扩展版/15电机架.stl
14.6 x 27.0 x 27.0

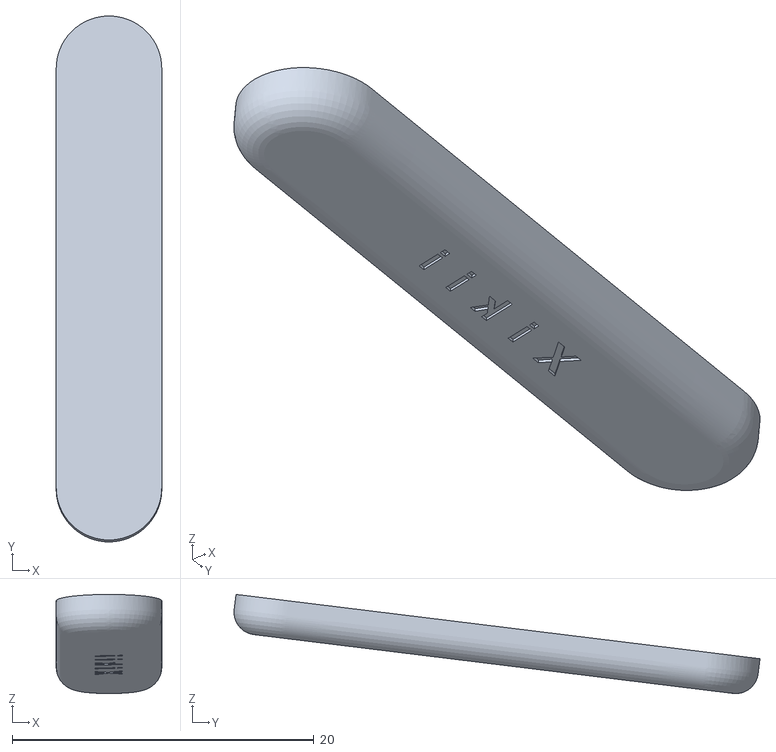
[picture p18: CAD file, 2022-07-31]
5.3D Model/瀚文基础版/06防滑脚垫.stl
7.00 x 34.9 x 6.57

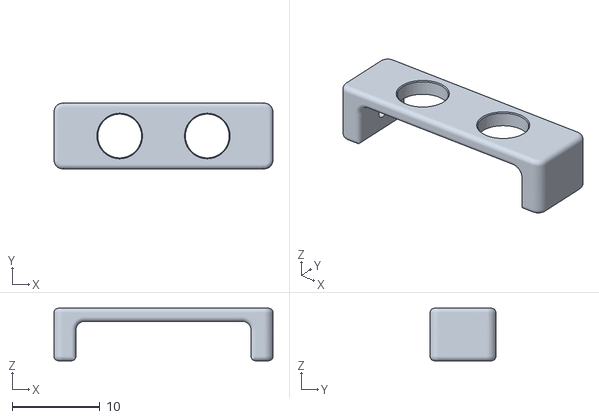
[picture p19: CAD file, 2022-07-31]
5.3D Model/瀚文扩展版/11按键罩.stl
25.0 x 7.50 x 6.00

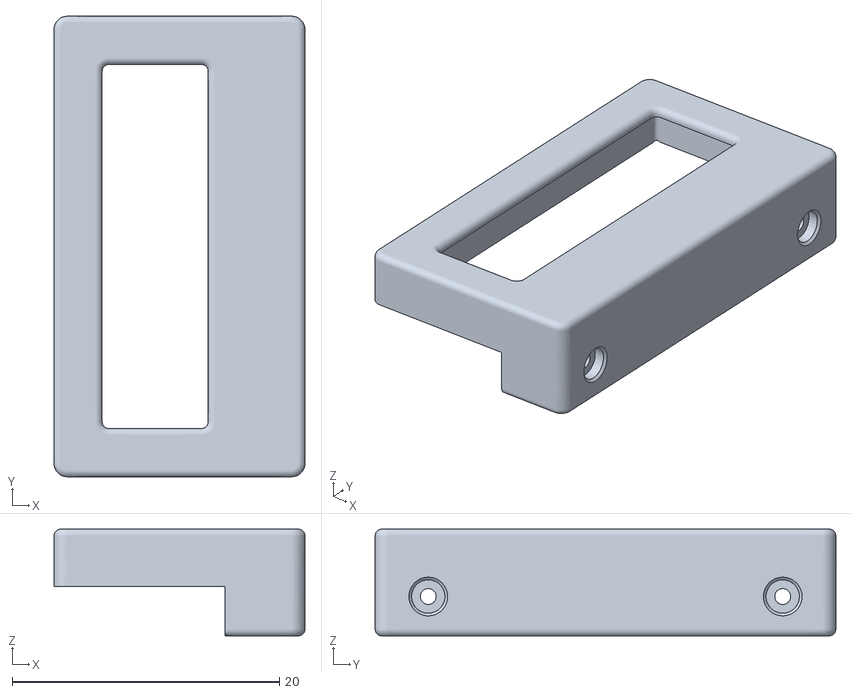
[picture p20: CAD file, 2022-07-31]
5.3D Model/瀚文扩展版/10小屏幕罩.stl
18.8 x 34.5 x 8.00

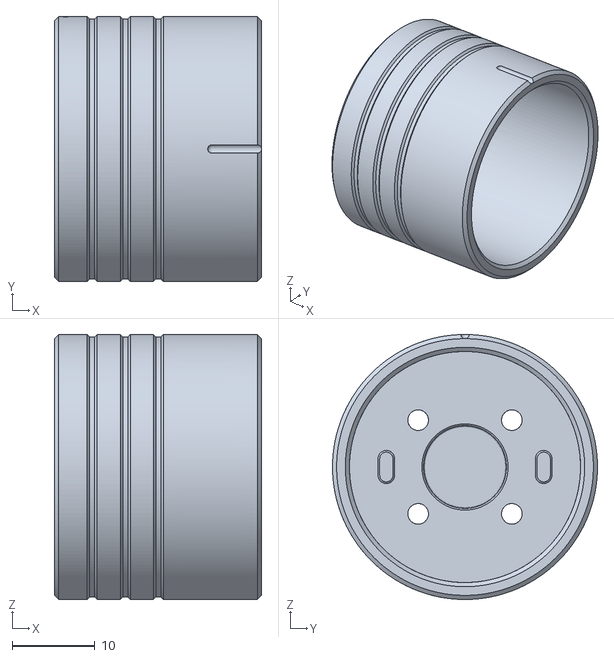
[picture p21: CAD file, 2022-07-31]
5.3D Model/瀚文扩展版/13旋钮壳.stl
25.0 x 32.0 x 32.0

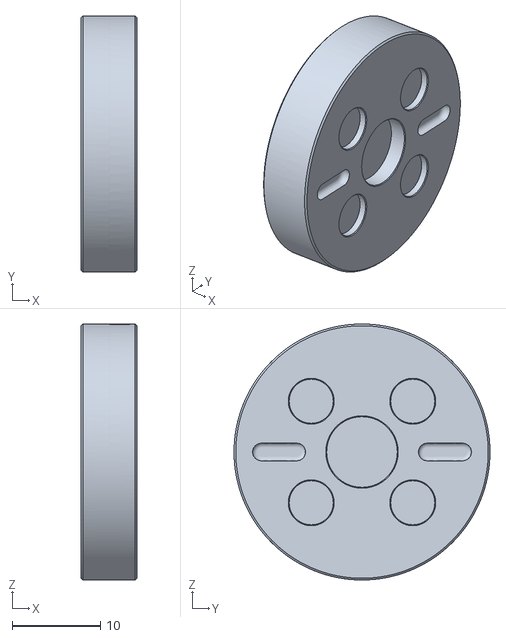
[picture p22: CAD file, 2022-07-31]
5.3D Model/瀚文扩展版/14旋钮盖.stl
6.32 x 29.0 x 29.0

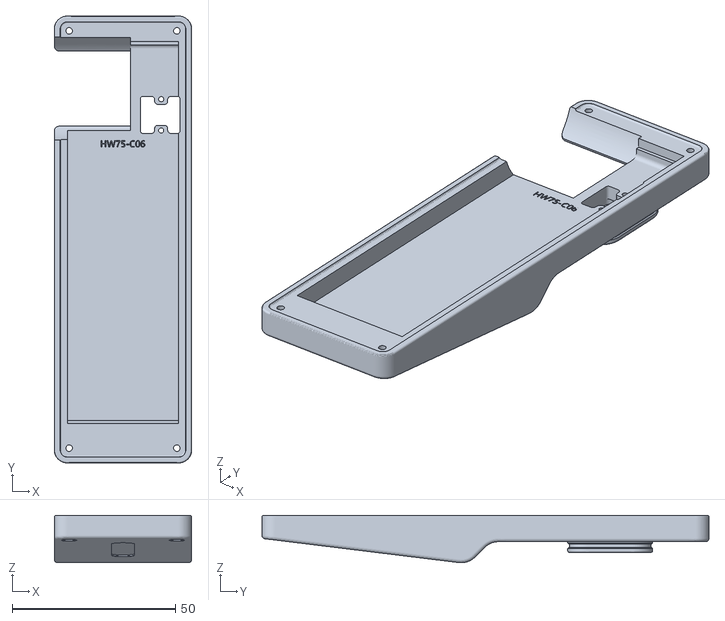
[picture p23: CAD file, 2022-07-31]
5.3D Model/瀚文扩展版/09模块底壳.stl
42.1 x 137.0 x 14.6

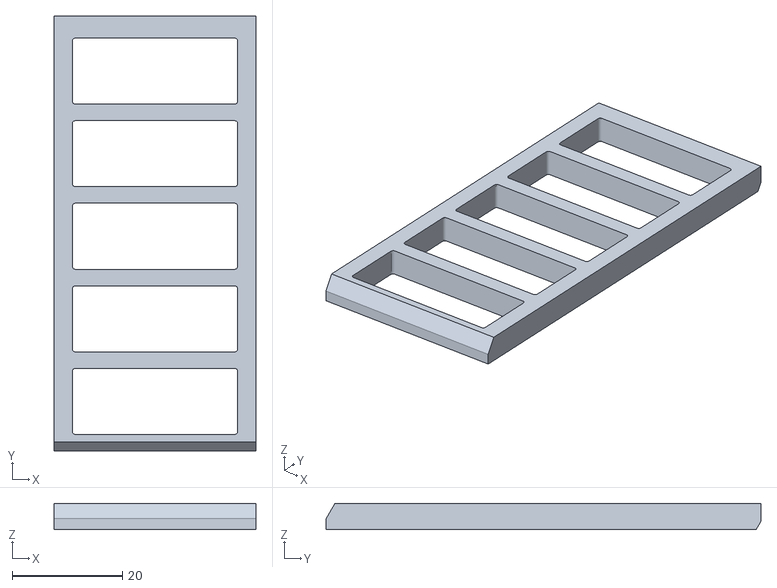
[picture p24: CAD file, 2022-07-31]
5.3D Model/瀚文扩展版/17大屏幕垫块.stl
36.7 x 79.0 x 4.78

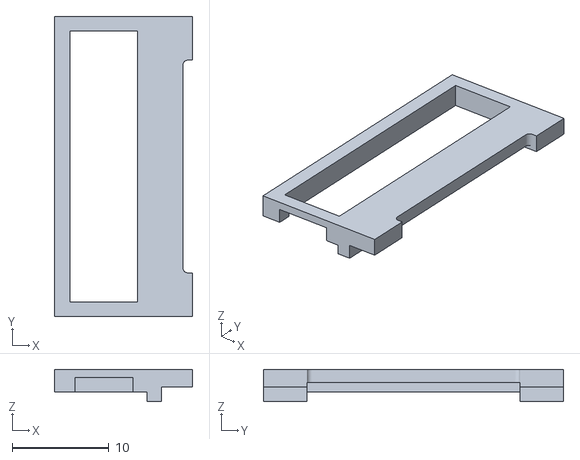
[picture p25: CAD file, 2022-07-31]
5.3D Model/瀚文扩展版/16小屏幕垫块.stl
14.3 x 31.0 x 3.33

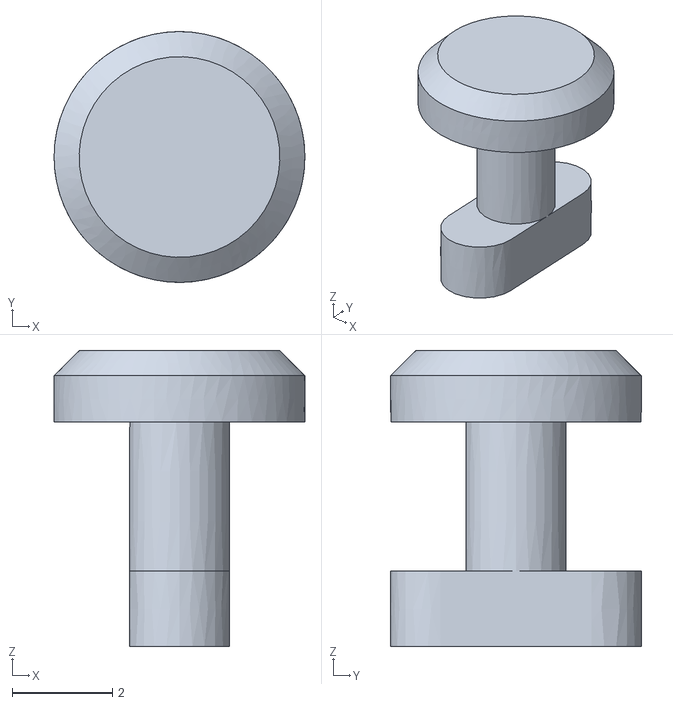
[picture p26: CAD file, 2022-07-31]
5.3D Model/瀚文扩展版/12按键.stl
5.00 x 5.00 x 5.90

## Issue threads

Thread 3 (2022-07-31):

力创 link 404

urfdvw, 2022-07-31:
https://oshwhub.com/pengzhihui/helloword-smart-keyboard
目前不能访问的样子
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

peng-zhihui, 2022-07-31:
新版PCB还在打样验证，确认无误后会更新的哈，可以等一阵子

yi-Xu-0100, 2022-08-30:
https://oshwhub.com/pengzhihui/b11afae464c54a3e8d0f77e1f92dc7b7

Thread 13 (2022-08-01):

屏幕可以替换成无线模式吗

MikasaEureka, 2022-08-01:

MikasaEureka, 2022-08-01:
如果换屏幕的话，该怎么选择呢

songzhishuo, 2022-08-01:
> 如果换屏幕的话，该怎么选择呢

如果是点阵其实只要是u8g2支持的，理论上都是可以的以很小的改动移植上去的

MikasaEureka, 2022-08-02:
> 什么叫无线模式的屏幕？
>
> Dynamic 上有两块屏幕，一块是 OLED，走 I²C 的。另一块是墨水屏，走 SPI 的。它们都接到了 Dynamic 中的 STM32 上。

emmm，我的意思就是屏幕和键盘的连接不通过有线接口，通过无线接口投射

MikasaEureka, 2022-08-02:
> > 如果换屏幕的话，该怎么选择呢
>
> 如果是点阵其实只要是u8g2支持的，理论上都是可以的以很小的改动移植上去的

我是打算接一个10寸左右的扩展屏，，不知道换起来需要改哪些部分

jamesishandsome, 2022-08-02:
经典dilemma 改肯定是能改 问题在于作者肯定懒得浪费时间去做 你能问出这种问题 说明你也没有能力改

xingrz, 2022-08-02:
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

那你得另外挂一颗ESP32之类的无线芯片专门刷屏

MikasaEureka, 2022-08-02:
> 经典dilemma 改肯定是能改 问题在于作者肯定懒得浪费时间去做 你能问出这种问题 说明你也没有能力改

我正是因为不会，才来问的啊，，，

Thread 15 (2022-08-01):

是否可以提供一个关于按键扫描和Remap的讲解

songzhishuo, 2022-08-01:
程序中对按键扫描和remap没有很好的理解，keyMap的作用是什么？（按键&HID枚举的映射？）hidBuffer 中每一位的意义？可否有个文字说明的讲解。

fridyss, 2022-08-19:
> 程序中对按键扫描和remap没有很好的理解，keyMap的作用是什么？（按键&HID枚举的映射？）hidBuffer 中每一位的意义？可否有个文字说明的讲解。

根据HID Reprot 定义，按键值被映射对应的位，例如：第二字节，第4位置位，就是对应按键码 "A"的0x04数值。

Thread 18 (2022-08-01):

请问有没有大佬知道要哪些芯片啥的

weibi-briswich, 2022-08-01:

GongXiaoBei77, 2022-08-01:
主要的芯片就是
`STM32F103CBT6`
`STM32F4`
`AS5047P`
`74HC165`
`FD8288Q`
`LN3608`
`SDB628`
`XW06A`
`EMB12P03V`
(该部分均从README和Docs/Datasheet中得到信息)
更加具体的可以等立创开源出来,去立创看

xingrz, 2022-08-01:
键盘本体：

* STM32F103CBT6 主控
* 74HC165D 位移寄存器 (11 颗)
* XW06A 触控

底座：

* TP4056 电池充电芯片
* 一颗1分4的 USB Hub，具体型号没说

Dynamic 部分没仔细看。

Closed 2022-08-02.

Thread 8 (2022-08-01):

请问键盘支持热插拔吗？谢谢

Dr-Huang2006, 2022-08-01:

GongXiaoBei77, 2022-08-01:
这是当然的,请认真去看介绍视频

git-flyer, 2022-08-01:
啊，这，USB设备理所当然支持吧

Dr-Huang2006, 2022-08-01:
我的意思是键盘的轴支不支持热插拔，不是usb支不支持

GongXiaoBei77, 2022-08-01:
> 我的英文是键盘轴支不支持热封，不是的usb支不支持

事实上,原视频6分48秒中左右有展示过,而且不止一次出现,甚至在DOCS中也有明确的热拔插轴座的文档.

AkariiinMKII, 2022-08-03:
> 我的意思是键盘的轴支不支持热插拔，不是usb支不支持

请先浏览一遍[项目文件](https://github.com/peng-zhihui/HelloWord-Keyboard/blob/main/5.Docs/1.Datasheet/%E5%87%AF%E5%8D%8E%E7%83%AD%E6%8B%94%E6%8F%92%E9%94%AE%E8%BD%B4%E5%BA%A7.jpg)再提问，谢谢

Mo3et, 2022-08-08:
很明显是可以的 现在基本配合新手入门 都有热插拔轴座
README也有提到 是从Xikii的S98 改的 在这里问 还不如去xikii的群问

@Dr-Huang2006  请尽快自行Close 这个issue 有啥其他讨论去repo的Discussions里 这里主要是项目开发内容的issues 不要滥用issues！
（下面是Readme的引用）
> 注意：Issues里面是讨论项目开发相关话题的，不要在里面发无意义的消息，不然watch了仓库的人都会收到通知邮件会给别人造成困扰的！！！灌水可以在仓库的Discuss里讨论！

Closed 2022-08-08.

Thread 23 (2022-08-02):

Welcome to HelloWord-Keyboard Discussions!

anhy999, 2022-08-02:
### Discussed in https://github.com/peng-zhihui/HelloWord-Keyboard/discussions/21

<div type='discussions-op-text'>

<sup>Originally posted by **peng-zhihui** August  2, 2022</sup>
<!--
    ✏️ Optional: Customize the content below to let your community know what you intend to use Discussions for.
-->
## 👋 Welcome!
  We’re using Discussions as a place to connect with other members of our community. We hope that you:
  * Ask questions you’re wondering about.
  * Share ideas.
  * Engage with other community members.
  * Welcome others and are open-minded. Remember that this is a community we
  build together 💪.

  To get started, comment below with an introduction of yourself and tell us about what you do with this community.

<!--
  For the maintainers, here are some tips 💡 for getting started with Discussions. We'll leave these in Markdown comments for now, but feel free to take out the comments for all maintainers to see.

  📢 **Announce to your community** that Discussions is available! Go ahead and send that tweet, post, or link it from the website to drive traffic here.

  🔗 If you use issue templates, **link any relevant issue templates** such as questions and community conversations to Discussions. Declutter your issues by driving community content to where they belong in Discussions. If you need help, here's a [link to the documentation](https://docs.github.com/en/github/building-a-strong-community/configuring-issue-templates-for-your-repository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).

  ➡️ You can **convert issues to discussions** either individually or bulk by labels. Looking at you, issues labeled “question” or “discussion”.
-->
</div>

zgs225, 2022-08-03:
There's an English [post](https://kbd.news/Modular-keyboard-1569.html) that introduce the project. It should helpful to who can't read Chinese.

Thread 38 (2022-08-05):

关于锂电池供电问题

Fkaw-Yang, 2022-08-05:
锂电池使用的是单节3.7V还是两串的7.4V？升压的XL6019手册写到输入是5V~40V，如果是单节锂电池会不会有问题

xingrz, 2022-08-05:
底座部分充电IC是TP4056，只支持单节电池，充电截止电压是4.2V。
键盘部分的LDO是XC6210，最高输入电压是6.0V。
我认为是不支持两串的。

cakesauce, 2024-03-14:
为什么3.7V可以升上去12V呀

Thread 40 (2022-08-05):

Would it be possible to open-source the f3d project?

IsThisTheCrustyCrab-was-taken, 2022-08-05:
This would be cool because it would enable modification/extension of the design (I really like the concept but would like to simplify it a bit to look a bit more minimalist). Should also solve #17 .

ru8lq0005, 2022-08-05:
The author's friend is said that the pcb board still has some problems in solving, and around August 8 should be announced some other module design，please wait some days.

IsThisTheCrustyCrab-was-taken, 2022-08-06:
Ab okay, I will, thanks for the reply ^^

Closed 2022-08-06.

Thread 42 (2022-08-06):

up请问一下这个触摸条的问题

Wangzm007, 2022-08-06:
关于触摸条的设计,有一些疑惑想请教一下up:
- [1 ] 这个触摸PCB板上附着了一层白色材料是什么?是3D树脂还是涂色玻璃或者是乳白色的亚克力板?我想到就这几种.
- [2 ] 白色材料和触摸条PCB板分别有多厚呀?
- [3 ] 它们之间用的什么黏合剂,就普通胶水502之类的吗,普通胶水会不会影响触摸电容之类的.
异常喜爱这个触摸条,劳烦up如有闲暇的话可以解答一下我的疑惑哦,拜谢.

peng-zhihui, 2022-08-07:
切割的亚克力（Xikii准备用玻璃做）； PCB约薄越好；非导电材质就行

Closed 2022-08-06.

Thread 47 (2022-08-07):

关于PCB打板厚度问题  PCB打板厚度是嘉立创的默认1.6还是更薄

Ericbai0808, 2022-08-07:

peng-zhihui, 2022-08-07:
1.2mm

DakenYue, 2022-08-09:
请问是要需要匹配阻抗，用哪种结构呢

peng-zhihui, 2022-08-10:
这频率都没上100M，完全属于低速板，不用考虑阻抗匹配

DakenYue, 2022-08-10:
您好，您的邮件  张越   已收到！

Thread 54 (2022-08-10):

催更可以通过USB下载固件的Bootloader

GitHubIDforRoger, 2022-08-10:

xingrz, 2022-08-11:
https://github.com/HelloWord-REBUILD/stm32-hid-bootloader/releases

我自己 PORT 了一个。不难。

需要改一下链接脚本把程序往后挪 4KB。

hging, 2022-08-12:
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

cool.

YCF, 2022-12-21:
我已完成。
https://docs.keeb.pro/#/kb/HelloWorld75
整理完后开源。

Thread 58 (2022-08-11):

PCB Files?

KO-07, 2022-08-11:
This project looks amazing!
However, is there a method to turn the schematics into PCBs, if so how? or would it be possible to add Gerber files?

ZK-y53, 2022-08-11:
At present, the PCB is in the verification stage. We have received relevant information that the upload will be verified in the next week or two. Please wait patiently

KO-07, 2022-08-11:
Thank you for the update!

Closed 2022-08-11.

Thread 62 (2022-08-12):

建模

ZK-y53, 2022-08-12:
我重新建模了一份HW75，目前正在加工验证，有需要的可以问我

zhdjet, 2022-08-12:
你好，硬件的工程文件能分享一下吗？谢谢！

xuexuedan, 2022-08-12:
你好，如果可以请发我一份，大家一起探讨 ,xuexuedan@qq.com,谢谢

Viggo77, 2022-08-12:
您好 请问文件可以分享一下嘛 不胜感激 邮箱 viggo3291100181@163.com

1074566721, 2022-08-16:
文件能分享一下嘛？我的邮箱1074566721@qq.com  谢谢

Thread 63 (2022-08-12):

屏幕和电池的选择

zhen2000, 2022-08-12:
请问，电池，墨水屏和oled在哪里买呀？型号是什么？谢谢！

wlzxzq, 2022-08-13:
墨水屏和oled的型号是什么，查资料我看墨水屏应该是2.9寸的。
oeld不知道

peng-zhihui, 2022-08-13:
墨水屏2.9的，OLED是1.3的12832屏幕https://item.taobao.com/item.htm?id=571989710497

wlzxzq, 2022-08-14:
老师请问墨水屏2.9的的具体型号是E29A01 WF0290 BZ03 ？

peng-zhihui, 2022-08-14:
https://item.taobao.com/item.htm?id=563243412327

pthuang, 2022-08-14:
2.9寸的好像没货了

wlzxzq, 2022-08-16:
可以关掉问题了

pthuang, 2022-08-17:
这家店1.3寸的OLED好像分辨率是12864,1.1寸的是12836，买哪款？

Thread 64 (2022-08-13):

关于HC165扫描顺序的问题

zhdjet, 2022-08-13:
@peng-zhihui
考虑原理图中箭头指的那个按键，这个按键可以在PCB的任意位置，但我们可以看到它是从左到右（按74HC165的连接顺序，也即移位扫描顺序）的第9颗，因此它的编号为9.

以上[稚晖君]的表述可能要改一下：图片中的箭头应该持续到第10个按键，也就是图片中那个按键的右侧那个；
（按74HC165的连接顺序，也即移位扫描顺序）的第9颗，-->应该为：（按74HC165的连接顺序，也即移位扫描顺序）的第10颗，因为扫描顺序是从0开始的，因此它的编号为9。

peng-zhihui, 2022-08-14:
是的，标注错了，我改一下

Closed 2022-08-14.

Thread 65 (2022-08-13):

关于CLion在Mac下的环境配置参考资料

hiifong, 2022-08-13:
详见:[clion-embedded-arm](https://github.com/elmot/clion-embedded-arm)

1552980358, 2022-08-15:
看看回头能不能移植到PlatformIO吧

ZK-y53, 2022-09-21:
https://gitee.com/xmja/clion-mac-stm32?_from=gitee_search这是我做的，亲测有效（Mac M1pro）

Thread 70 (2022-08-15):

pageup键用不了

xiaohaha23, 2022-08-15:
我测量pcb阻值正常，但就是那个键用不了，换成别的映射也不行

KerrLiu, 2022-08-15:
Oh!我还是刚弄好外壳，仁兄你好快

xiaohaha23, 2022-08-15:
根据原理图画的

KerrLiu, 2022-08-15:
好家伙被秀到了，之前发过一版工程文件

xiaohaha23, 2022-08-15:
有人知道怎么处理吗，硬件万用表测没问题

wlzxzq, 2022-08-16:
>

去哪里获取工程文件，是可以直接pcb打印的么

xiaohaha23, 2022-08-17:
> 去哪里获取工程文件，是可以直接pcb打印的么

自己根据原理图画呢

Closed 2022-08-15.

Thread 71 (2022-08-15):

新问题，为什么吧任何键赋零层的0值就失效了

xiaohaha23, 2022-08-15:
现在问题源就是，零层的0值，无论赋予任何一个1层映射都无效，但当切换为二层映射就有效，初步怀疑是一层0值无意义导致，得通过二层去触发一层的映射，硬件检查无任何问题

peng-zhihui, 2022-08-19:
映射是这样的，0层是必然会执行的，后续的1~N层只会执行一个，也就是说你选的2层那么最终就是先映射0层，然后映射2层，所以你描述的这个问题应该是代码有点小bug，晚点有空我调一下

0xCC0x01, 2022-08-23:
pageUP的bug，应该跟按键定义有关：

1. keymap[KEYMAP_NUM][IO_NUMBER]，有5层映射，每层88个（82个按键+6个Touchpad）
2. 但在定义每层映射时，实际只有83个值，后面的几个默认初始化了0
3. 默认给的0值，恰好是pageUP对应的IO pin

可以尝试下，把keymap 0层映射，最后面的几个值补充完整，应该能搞定，比如：
int16_t keyMap[KEYMAP_NUM][IO_NUMBER] = {
// The first layer, used for aligning 74HC165 IO pins to PCB key layout
{67, 61, 60, 58, 59, 52, 55, 51, 50, 49, 48, 47, 46, 3,
80, 81, 64, 57, 62, 63, 53, 54, 45, 44, 40, 31, 26, 18, 2,
19, 70, 71, 66, 65, 56, 36, 37, 38, 39, 43, 42, 41, 28, 1,
15, 74, 73, 72, 68, 69, 29, 30, 35, 34, 33, 32, 24, 0,
14, 76, 77, 78, 79, 16, 20, 21, 22, 23, 27, 25, 17, 4,
13, 12, 8, 75, 9, 10, 7, 11, 6, 5,
82, 83, 84, 85, 86, 87} //最后的几个值，不要空着

我没硬件，没有尝试，有板子的同学可以试下

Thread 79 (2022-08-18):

稚晖君你好，我在复刻瀚文，发现page up键无法使用，检测了下硬件没有问题，可能是程序哪里的bug,感谢回复！

DOCTOROLIVE, 2022-08-18:
page up 键无法使用

peng-zhihui, 2022-08-18:
是一个bug，我晚点调试一下

0xCC0x01, 2022-08-23:
pageUP的bug，应该跟按键定义有关：
1. keymap[KEYMAP_NUM][IO_NUMBER]，有5层映射，每层88个（82个按键+6个Touchpad）
2. 但在定义每层映射时，实际只有83个值，后面的几个默认初始化了0
3. 默认给的0值，恰好是pageUP对应的IO pin

可以尝试下，把keymap 0层映射，最后面的几个值补充完整，应该能搞定，比如：
int16_t keyMap[KEYMAP_NUM][IO_NUMBER] = {
            // The first layer, used for aligning 74HC165 IO pins to PCB key layout
        {67,  61, 60, 58, 59, 52, 55, 51, 50, 49, 48,  47,  46,  3,
            80,           81,    64,    57,    62,    63,    53,    54,    45,    44,    40,    31,    26,    18,        2,
            19,  70, 71, 66, 65, 56, 36, 37, 38, 39, 43, 42,           41,            28,        1,
            15,       74, 73, 72, 68, 69, 29, 30, 35, 34, 33,         32,    24,    0,
            14,         76, 77, 78, 79, 16, 20, 21, 22,    23,     27,    25,          17,       4,
            13,        12,       8,        75,    9,         10,        7,  11,         6,          5,
            82, 83, 84, 85, 86, 87} //最后的几个值，不要空着

JiumiYao, 2022-08-23:
问题具有完全可见的复现能力，看到了楼上[user:[0xCC0x01](https://github.com/0xCC0x01)]的方法补充了映射最后几个值，问题得到了解决。不过在游戏中按键的绑定似乎仍存在问题，测试Steam平台CS:GO和EPIC平台堡垒之夜均无法正常使用点击绑定，不过网页和输入法的确没问题。游戏本身问题待查。

Gralerfics, 2022-08-24:
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

您好，我觉得您的解答非常有道理，应该是与初始化的 0 有关，但是还是不太想得明白为什么会导致 Page Up 失灵。缺少的五个值对应触摸条的后五个触点，如果被初始化为 0 是否应该只是代表多出了五个 Page Up 键（因为 remapBuffer[i] |= 0x80 >> j; 用的是或等于，似乎不会干扰相同功能键的使用）？手上还没有硬件可以尝试，只能空想，希望能得到解答，谢谢 orz。

0xCC0x01, 2022-08-25:
> 您好，我觉得您的解答非常有道理，应该是与初始化的 0 有关，但是还是不太想得明白为什么会导致 Page Up 失灵。缺少的五个值对应触摸条的后五个触点，如果被初始化为 0 是否应该只是代表多出了五个 Page Up 键（因为 remapBuffer[i] |= 0x80 >> j; 用的是或等于，似乎不会干扰相同功能键的使用）？手上还没有硬件可以尝试，只能空想，希望能得到解答，谢谢 orz。

我也没有硬件，只是对着代码看的猜测，发出来也是想请有板子的这位兄弟验证下。

0xCC0x01, 2022-08-25:
你提到的`remapBuffer[i] |= 0x80 >> j`确实是或，不干扰其他的，但后面还有一段hidBuffer相关的代码：
```
index = (int16_t) (keyMap[_layer][i * 8 + j] / 8 + 1);
bitIndex = (int16_t) (keyMap[_layer][i * 8 + j] % 8);
……

if (remapBuffer[i] & (0x80 >> j))
      hidBuffer[index + 1] |= 1 << (bitIndex);
```
layer1最后的几个值也是0，就相当于在hidBuffer中把keycode为0的按键也放进去了，keycode 0是Reserved。
也就是说按下pageUP时，实际hidBuffer中包含了Reserved以及pageUP，不知道操作系统会如何处理，
如果操作系统认为包含了Reserved的按键信息是无效的，丢弃掉不处理，那pageUP也就无效了

没有验证，纯看代码猜想。

JiumiYao, 2022-08-25:
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

您好！您这个方法可以解决了pageup这个问题！（其实几天前看到您评论这个就弄了解决了）但是最后我删评了主要是因为部分游戏还是无法识别pageup，目前我试过了有csgo、apex、堡垒之夜都没办法在设置页面通过点击绑定pageup按键。但是在office、chrome网站和其他我常用的几款软件都是可以的，无法识别的均是游戏，所以当时就先删评想解决这个问题。但是研究了几天还是没啥思路，不知您是否有看法和解决的方案？

JiumiYao, 2022-08-25:
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

感觉像是驱动的问题？但是这个方面我不太懂，不知从哪里入手。

0xCC0x01, 2022-08-25:
> 您好！您这个方法可以解决了pageup这个问题！（其实几天前看到您评论这个就弄了解决了）但是最后我删评了主要是因为部分游戏还是无法识别pageup，目前我试过了有csgo、apex、堡垒之夜都没办法在设置页面通过点击绑定pageup按键。但是在office、chrome网站和其他我常用的几款软件都是可以的，无法识别的均是游戏，所以当时就先删评想解决这个问题。但是研究了几天还是没啥思路，不知您是否有看法和解决的方案？感觉像是驱动问题，但是不太懂这方面开发，不知从哪里入手。

如你所说，在office、网页等应用pageUP已经可以使用，那我觉得就跟固件没什么关系了。至于游戏无法绑定pageup，这个我不了解，你可以试下其他的键盘是否有同样游戏的问题，个人认为不是键盘固件的问题。

ps: 羡慕你们都已经拿到键盘了，太快了…… 我才上了PCBA的车，东西估计还要几周才能到。

JiumiYao, 2022-08-25:
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

哈哈，我朋友是出国在瑞士那边留学，留下来给罗技做工程师了，稚晖君大佬开源了大部分东西，小部分问题他都帮我设计好了。我表弟刚好是干外设厂的，所以制造也没什么难题哈哈哈（主要是可以白嫖大赚特赚）。我自己研究研究这个问题吧，之前达尔优A98也出现-/_和=/+键chrome和打字上没问题，游戏死活没反应。最后给大家发了个新驱动解决了，我去打听打听~也可能是我自己硬件的问题，感谢您的解答和建议哈哈哈~

Gralerfics, 2022-08-25:
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

感谢解答，之前是忽略了后面的层 hhh，到手再试试了。祝好。

MuYunyun, 2022-10-08:
@JiumiYao @0xCC0x01 羡慕大佬们，个人硬件方面小白，硬件部分是否可以帮忙开发(有偿)或者推荐啥上手文章。。个人想先实践下软件方面部分。。

peng-zhihui, 2022-10-11:
已经修复了

Closed 2022-10-11.

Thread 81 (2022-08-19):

HID report发送之前对按键按下的判断？

0xCC0x01, 2022-08-19:
请教个问题：
发送HID report之前，没有判断是否有按键按下，这样即便任何按键都没按，也会固定发送，1ms一次
是否应该加上判断，有按键再发送report？

extern "C" void OnTimerCallback() // 1000Hz callback
{
    keyboard.ScanKeyStates();  // Around 40us use 4MHz SPI clk
    keyboard.ApplyDebounceFilter(100);
    keyboard.Remap(keyboard.FnPressed() ? 2 : 1);  // When Fn pressed use layer-2

    // Report HID key states
    USBD_CUSTOM_HID_SendReport(&hUsbDeviceFS,
                               keyboard.GetHidReportBuffer(1),
                               HWKeyboard::KEY_REPORT_SIZE);
}

fridyss, 2022-08-19:
>

没按键按下时，需要清发0， 清除端口缓冲，不然主机会认为端口有数据， 会一直请求数据。

0xCC0x01, 2022-08-22:
> >
>
> 没按键按下时，需要清发0， 清除端口缓冲，不然主机会认为端口有数据， 会一直请求数据。

再请教下，是发一次0，清除缓冲就可以，还是在没有按键按下时，持续发0？

peng-zhihui, 2022-08-22:
HID是中断传输，主机定时读取数据的，有没有按键都需要上报，建议了解一下USB HID相关协议和报文格式。

Closed 2022-08-22.

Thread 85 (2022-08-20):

关于20号更新的立创工程文件问题

zhdjet, 2022-08-20:
@peng-zhihui
今天更新的立创工程文件中的键盘主体的PCB的Delete键位的封装反了,可能要旋转180度,请更新立创工程,谢谢!

wang-yi-yuan, 2022-08-20:
能不能发Gerber文件呢，立创里好多错误（比如GND消失，铺铜消失，部分焊盘悬空未连接上网络等）

peng-zhihui, 2022-08-20:
文件版本上传问题，已经修复了以最新的为准。覆铜没有消失只是没有显示，你设置一下就行了。

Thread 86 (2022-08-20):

请问视频中拓展区的功能会开源吗，还有20号更新的文件电路部分有一些问题

tklovejk, 2022-08-20:
大佬您好，关于拓展区的电机以及oled显示功能，没有找到相关的程序，麻烦问一下这部分代码会开源吗？还有20号更新的电路部分好像有很多问题，是导入立创eda导致的吗，还是上传错版本了。谢谢大佬

peng-zhihui, 2022-08-20:
OLED我视频中是临时写的几个测试程序，不是封装好的代码，这个会后续封装好后更新；目前你也可以直接用U8g2的API绘制屏幕内容。

 文件版本上传问题，已经修复了以最新的为准。

DOCTOROLIVE, 2022-08-23:
> 大佬您好，关于拓展区的电机以及oled显示功能，没有找到相关的程序，麻烦问一下这部分代码会开源吗？还有20号更新的电路部分好像有很多问题，是导入立创eda导致的吗，还是上传错版本了。谢谢大佬

你好，请问一下，稚晖君预编译的扩展模块的bin文件能点亮OLED，墨水屏显示瀚文么，有他B站视频演示的效果么？

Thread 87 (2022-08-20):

「基础版」与「扩展版」的区别与升级可能

XieJinYan1127, 2022-08-20:
背景
1. 想先实现一个简单的键盘，完成后再进行扩展成扩展版

问题
1. 基础版是否只包含一个普通键盘的功能
2. 基础版是否可以后续升级为扩展版
3. 基础版升级到扩展版的方法是否是以下
a. 重新制作支脚（包括外壳与PCB）
b. 制作扩展模块
*键盘部分无需改动？

tklovejk, 2022-08-21:
1、基础版只有键盘功能
2、可以
3、a、不需要，但需要第一次预留弹簧针位置
      b、需要
键盘无需改动

xingrz, 2022-08-21:
根据之前 Xikii 在直播中的说法，键盘本体是完全一样的。扩展版的区别仅仅在于支脚。不同尺寸的扩展模块搭配不同长度的支脚。

XieJinYan1127, 2022-08-21:
> 根据之前 Xikii 在直播中的说法，键盘本体是完全一样的。扩展版的区别仅仅在于支脚。不同尺寸的扩展模块搭配不同长度的支脚。

就是说，如果升级的话，或者更换扩展模块的话，需要重新制作支脚（包括PCB和外壳）？

xingrz, 2022-08-21:
> > 根据之前 Xikii 在直播中的说法，键盘本体是完全一样的。扩展版的区别仅仅在于支脚。不同尺寸的扩展模块搭配不同长度的支脚。
>
> 就是说，如果升级的话，或者更换扩展模块的话，需要重新制作支脚（包括PCB和外壳）？

是这么说。反正扩展模块和替换的支脚是一起卖的。

peng-zhihui, 2022-08-22:
这个跟本仓库内容无关，我不卖东西的，开团的事情去找xikii咨询就好了

peng-zhihui, 2022-08-22:
基础版和扩展的模块是不耦合的，可以单独使用

Closed 2022-08-21.

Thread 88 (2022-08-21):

更新的 PCB 工程 TypeC 集线器弹簧针所在面的问题

Gralerfics, 2022-08-21:
TypeC 集线器上的六脚弹簧针座好像应该朝另一面……？（不过应该不影响焊接 emm）

Closed 2022-10-01.

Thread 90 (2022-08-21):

集线器-HUB2 PCB问题

NGXAS, 2022-08-21:
“文件中间铣槽连接位太小，会断板，需麻烦您帮忙加宽到最窄4mm以上”嘉立创审核如是说，没法上图，审核反馈图就是板子的左右两边角落的槽孔

xingrz, 2022-08-22:
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

你是说这两个地方吧，我也觉得不合理（捂脸）

感觉可以换成卧贴的封装

NGXAS, 2022-08-23:
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

对……

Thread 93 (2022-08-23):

关于在翰文87的原理图基础上扩展配列的问题请教

zhdjet, 2022-08-23:
@peng-zhihui
您好,如果我想在此工程的基础上扩展配列;在瀚文键盘的原理图的基础上增加HC165的数量,请教增加的HC165应该要串连在哪个位置?

1.直接串连在XW06A的6个触摸按键的后面;

2.串连在XW06A的6个触摸按键前面(即键盘配列和触摸按键的中间);

3.直接在原理图的最前面增加.

谢谢!

peng-zhihui, 2022-08-23:
都可以，PCB的165芯片连接顺序和按键走线连接都可以是随机的，连完之后修改代码里的0层映射就行；不过从功能统一性角度来说，【2】是最合理的。

zhdjet, 2022-08-23:
谢谢!
另外再请教一下:在工程代码的0层映射中的第83个键(此层的最后一个[82]:85),实际键盘配列是82个键位,那这个85是不是6个触摸按键中的1个?工程中触摸按键有6个键位,在Smart Keys中有定义,但是工程中并未使用;这个6个触摸键位是不是可以分别定义使用,还是定义成一个整体使用?

zhdjet, 2022-08-23:
还有一个关于增加HC165扩展配列的问题:HC165悬空的引脚(HC165的IO总数大于实际配列键位数量)对键位的扫描有影响吗?谢谢!

xingrz, 2022-08-23:
> HC165悬空的引脚(HC165的IO总数大于实际配列键位数量)对键位的扫描有影响吗?

我之前用面包板随便试了一下，悬空不上拉的话读到的是低电平（相当于按下状态）。没仔细看代码，不确定不加0层映射的情况下一直处于低的位会怎么处理。但是既然用排阻的话，我觉得把不用的引脚都上拉也没坏处 😎

zhdjet, 2022-08-24:
谢谢!
假设我做了一个17键的数字小键盘(可拆装的),0层也映射了,如果我把数字小键盘拆了不装,只用主体键盘,那0层映射层是不是还要重新定义一下?如果不定义会不会有影响?

xingrz, 2022-08-24:
> 如果我把数字小键盘拆了不装,只用主体键盘,那0层映射层是不是还要重新定义一下?如果不定义会不会有影响?

从原理上分析：取决于主体上最后一个HC165的SI脚的电平（抱歉，现在手边暂时没资料，不确定悬空的情况下它是低还是高）。如果默认是高就还好，相当于没按下；如果默认是低那就相当于小键盘全被按下了。我觉得可以给最后一个SI脚加个上拉。

peng-zhihui, 2022-08-24:
不影响，所有按键都有排阻上拉，不接按键就是默认扫出来高电平（在代码中做了位反转所以会得到0）

zhdjet, 2022-08-24:
> 不影响，所有按键都有排阻上拉，不接按键就是默认扫出来高电平（在代码中做了位反转所以会得到0）

那如果我在此工程原理图的的6个触摸按键后面,再串联2片HC165来扩展小数字键盘,这个小键盘是分离式的,通过接口与键盘主体对接,而这2片HC165是焊在小键盘的PCB上的,工程代码中肯定是要把小数字键盘的键位在0映射区中映射的,如果小数字键盘不与键盘主体连接时,即只使用键盘主体,也就是主电路中不存在后扩的2片HC165,

1.此时0映射区要重新定义吗?

2.对整体的键位扫描会有影响吗?

3.如果上面这种情况对键位扫描有影响,请问在硬件电路或工程代码上要怎么处理?

谢谢!

peng-zhihui, 2022-08-24:
扫多少按键是代码决定的，主控并不知道你接了多少165，SPI给一个时钟脉冲就会读出一位信号，所以你把最后一个165的级联引脚拉高就行了，相当于不管主控读几个按键，只要超过实际物理按键数量，结果就都是1.

zhdjet, 2022-08-24:
好的,谢谢指教!我再琢磨琢磨;这两天把板子画好,有了实物再请教.非常感谢!

1074566721, 2022-09-20:
你好，关于更改配列的事，我们可以合作一下，我负责修改外壳模型，你改pcb，如果有意请添加我的qq 1074566721我们详聊

1074566721, 2022-09-20:
> 好的,谢谢指教!我再琢磨琢磨;这两天把板子画好,有了实物再请教.非常感谢!

你好，关于更改配列的事，我们可以合作一下，我负责修改外壳模型，你改pcb，如果有意请添加我的qq 1074566721我们详聊

STAR5847, 2023-02-24:
您好，我想在U10的第4脚第3脚第14脚第13脚第12脚第11脚上接出6个键位，这样就凑出了87个键位，请问可以怎么接嘛？

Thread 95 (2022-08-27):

主控板PCB直接在立创EDA里点PCB下单，打出来的板子轴体和rgb灯的孔都没开

Jack918, 2022-08-27:
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

嘉立创的回复是

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

是我下单的时候设置有问题吗

yangbo254, 2022-08-27:
专门去确定了下，目前立创EDA开源的地址，[稚晖](https://github.com/peng-zhihui)确实把led、轴孔的开孔画在了outline层，然后在outline2层又画了个只有外形的框，在机械层drl，仅画了你图片板子里面目前开孔的孔。
根据嘉立创19年出的免责规则，就是有drl认drl不认多outline的这条规则，看起来还真是稚晖画错了。。。

peng-zhihui, 2022-08-27:
这个是下单时间比较早吧？后面大量的单都是用这个文件做的，嘉立创应该是知道的。不过确实是第一次用立创EDA做项目，玩得还不是特别熟，后续我修改一下加个注释。

zhangsanbin, 2022-08-28:
建议花 3 元，勾选确认生产稿，再进行二次检查。

Chenshengshu, 2022-08-28:
我也遇到这个问题了，没做修改孔没开

QGB, 2023-08-22:
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
现在没有顺丰包邮了

QGB, 2023-08-22:
https://www.jlc.com/portal/q7i41203.html

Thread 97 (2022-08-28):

F9问题

askyuan, 2022-08-28:
按下f9会触发f9、ctrl、c、v等几个按键，检测了焊接没有问题，重新焊接了一块pcb还是有这个问题，触发时ctrl、c、v这三个按键并没有电平变化，请问有遇到相同问题的兄弟没？需要怎么解决？或者是什么原因造成的？

wlzxzq, 2022-08-28:
电路焊接问题

askyuan, 2022-08-28:
那为什么按下ctrl、c、v这三个键不会触发f9呢

xuexuedan, 2022-08-28:
问题很显然，是165芯片没有焊接好，有短路

askyuan, 2022-08-30:
问题找到了，我电脑问题，其他键盘f9也会这样

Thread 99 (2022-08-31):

STP

Ku-hsun, 2022-08-31:
請問有人可以傳stp文件到這邊嗎?
沒有手機號碼無法註冊帳號。

Adios1993, 2022-08-31:
[](url)
[瀚文全套模型STEP.zip](https://github.com/peng-zhihui/HelloWord-Keyboard/files/9459674/STEP.zip)

Ku-hsun, 2022-08-31:
十分感謝

Ku-hsun, 2022-08-31:
>
請問能再傳PCB LAYOUT 檔案嗎?

Ku-hsun, 2022-08-31:
@Adios1993 請問能再傳PCB LAYOUT 檔案嗎?

LIUHAITAO-CH, 2022-10-03:
>新上传的stp格式的文件，我打开以后，看着像一个整体的键盘模型，我想找淘宝cnc加工，直接给这个stp文件，不行吧，还有就是键帽不需要cnc加工吗，直接买现成就可以吗？有人推荐的键帽链接吗？谢谢

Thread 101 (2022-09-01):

关于通信方面

371979859, 2022-09-01:
请问：
1、关于扩展版是如何设置电机的参数是直接单独调试好后保存在mcu里，还是可以使用usb通信来进行调整呢？后续会添加吗？
2、墨水屏的的图片数据上位机是怎么样传输的呢，目前usb口只有这一个功能吗？后面是否会开源上位机源码呢？
3、关于扩展版中使用的通信协议，个人感觉有点难理解，是否有什么学习的途径呢？
4、上位机只使用了libusb库吗？

还望大佬指点一二，谢谢！

peng-zhihui, 2022-09-02:
1.保存flash里面的，源码里有模拟eeprom的代码，只是还没有调用，可以自己看一下
2.usb bulk传输，会开放SDK代码
3.零基础的话去看《圈圈带你学USB》入门一下USB通信
4.目前是，后期会有很多三方库比如Qt、OpenCV之类的

371979859, 2022-09-02:
> 1.保存flash里面的，源码里有模拟eeprom的代码，只是还没有调用，可以自己看一下 2.usb bulk传输，会开放SDK代码 3.零基础的话去看《圈圈带你学USB》入门一下USB通信 4.目前是，后期会有很多三方库比如Qt、OpenCV之类的

谢谢稚晖君的回复

但是关于第三点其实我想问的是关于protocol.c/.hpp中使用的传输json格式数据的协议
我试着在PC端使用usb bulk发送“test_function”但是并没有反应，是否是我的使用方式错了呢？

另外关于打印浮点数的问题，在更改了CMakeList.txt后仍然无法使用printf直接打印，是否有另外的解决方法呢？

期待项目的后续发展！

DOCTOROLIVE, 2022-09-16:
>

<圈圈教你玩USB>好像，哈哈

Closed 2022-09-19.

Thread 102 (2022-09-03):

关于墨水屏驱动电路

txp666, 2022-09-03:
亲测 需要短接 墨水屏9 10引脚  并 更换 C6为10UF
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

DOCTOROLIVE, 2022-09-03:
你好,我短接了9 10脚 不亮,想不通这个电容参数有啥影响,  您这个屏幕型号具体是哪个啊

txp666, 2022-09-03:
> 你好,我短接了9 10脚 不亮,想不通这个电容参数有啥影响, 您这个屏幕型号具体是哪个啊

我是优信电子买的那个

WinstonZBB, 2022-10-18:
你好，OLED用的哪款？我这边找的OLED都是30Pin的引脚

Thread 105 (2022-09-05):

关于扩展配列问题的请教

zhdjet, 2022-09-05:
@peng-zhihui
您好,现在扩展工程已经焊接调试完成,遇到如下几个问题请教:

1.第0号健位不响应(即扫描的起始键)

2.KeyMap的顺序只能在瀚文工程的基础上往下接,而且得照着上面Keycode定义好的键名增加,如果实物键盘的键位布局重新排列0层\1层\2层,实际键盘的输出跟实际键位编号是乱掉的.(感觉它是按照一个设定的标准布局走的)不能随意打乱)

3.关于Keycode数组的键名的定义,有没有参考的定义表或资料?假如我想在数字小键盘上增加:
一对小括号为一个键,
一对大括号为一个键,
一个打开计算器的快捷键,
一个分号键
或者再增加一些特殊的键值,要怎么处理?

4.增加FN键控制F1-F12定义多层控制功能,比如FN+F1打开浏览器等,要在哪里定义?

5.如果不要左侧的动态模组,可以增加旋转编码器控制音量或多媒体吗?

感谢百忙之中抽时间解惑答疑!

peng-zhihui, 2022-09-05:
1.早就已经修复了啊，pull最新代码
2.完全可以打乱，仔细理解一下代码
3.代码里有注释的，/**/里面的就是键名
4.加个if自己写个判断就行了
5.可以

zhdjet, 2022-09-06:
> 1.早就已经修复了啊，pull最新代码 2.完全可以打乱，仔细理解一下代码 3.代码里有注释的，/**/里面的就是键名 4.加个if自己写个判断就行了 5.可以

@peng-zhihui

大神,您好!

我现在把rgb灯取消了,增加了一个CapsLock的指示灯,就是在PB6引脚上接了下人LED,CapsLock按键的是按照FN键的方式接到PB1引脚上的,现在想切换大小写的时候这个指示灯能亮灭,指示键盘大小写的状态;
可是我憋了一天一夜也没写出来控制代码(照着HAL普通的按键控制灯的方式写的,但是不行),您能不能抽时间帮我写这个键盘按键控制MCU引脚上的LED的函数例程,我参考学习下下,非常感谢!!

zhdjet, 2022-09-06:
> 1.早就已经修复了啊，pull最新代码 2.完全可以打乱，仔细理解一下代码 3.代码里有注释的，/**/里面的就是键名 4.加个if自己写个判断就行了 5.可以

@peng-zhihui

大神,您好!

我现在把rgb灯取消了,增加了一个CapsLock的指示灯,就是在PB6引脚上接了下人LED,CapsLock按键的是按照FN键的方式接到PB1引脚上的,现在想切换大小写的时候这个指示灯能亮灭,指示键盘大小写的状态;
可是我憋了一天一夜也没写出来控制代码(照着HAL普通的按键控制灯的方式写的,但是不行),您能不能抽时间帮我写这个键盘按键控制MCU引脚上的LED的函数例程,我参考学习下下,非常感谢!!

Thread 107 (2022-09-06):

关于墨水屏上位机的使用，一直连接不上，除了zadig装驱动外还需哪些详细设置

DOCTOROLIVE, 2022-09-06:
关于墨水屏上位机的使用，一直连接不上，除了zadig装驱动外还需哪些详细设置

txp666, 2022-09-07:
就zadig给native那个装libusb驱动就可以了

DOCTOROLIVE, 2022-09-08:
> 就zadig给native那个装libusb驱动就可以了
您说的这个，我已经安装过了。不行 。会因为我那个24P的FPC连接线太长的缘故么，我用的30cm 的，折了好几道，

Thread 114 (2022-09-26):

PCB.

KO-07, 2022-09-26:
Hi sorry to be a bother  but I just wanted to ask if the pcb files are still being prototyped or if they are out elsewhere.

KerrLiu, 2022-09-27:
here!
https://oshwhub.com/pengzhihui/b11afae464c54a3e8d0f77e1f92dc7b7

KerrLiu, 2022-09-27:
Some problems with PCB files

KO-07, 2022-10-01:
Thank you .

KO-07, 2022-10-01:
Will they eventually be placed into github?

KerrLiu, 2022-10-02:
>

i don't konw

KO-07, 2022-10-02:
Oh that's ok thanks for the link tho

Closed 2022-10-14.

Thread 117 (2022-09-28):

关于 FN键位置的问题

zhdjet, 2022-09-28:
@peng-zhihui

在实际的使用中，发现 FN键的位置在原程序中必须映射在78号，对应FN键按下的检测 函数：

bool HWKeyboard::FnPressed()
{
    return remapBuffer[7] & 0x02;
}

中的[7］这个数字是对应的实际的键位吗？如果不是，要怎么计算？

如果对应的是实际键位，如果我把 FN放在35号键位，此键位也跟单片机引脚相连，那中括号中填入35，会报错。麻烦您抽时间给解答一下，非常感谢 ！

peng-zhihui, 2022-09-29:
1. 因为Fn键是固定的一般不会重映射，所以这个按键编码是hardcode的，可以自己根据remap函数里面的代码推算一下
2. 实际上你可以单独拉一根Fn的IO线到MCU引脚，这样就可以直接读取IO电平判断Fn了，我新版PCB里就是这么干的
3. 昨天刚更新的固件添加了通过按键名查找按键值的函数

zjzcpj, 2022-10-07:
由于对keymap进行了自行修改，可以利用新添加的KeyPressed函数来替代FnPressed的硬编码：
bool HWKeyboard::FnPressed()
{
    return HWKeyboard::KeyPressed(FN);   //Not sure yet
}
想确认一下可以这样用嘛

peng-zhihui, 2022-10-11:
可以

ThanatosSui, 2024-05-21:
大佬，我实验的自制键盘，还是无法正常识别FN按键。请教如何解决。谢谢

TheShallow, 2024-05-21:
这是来自小项的自动回复邮件。
 
邮件已收到

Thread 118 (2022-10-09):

关于CapsLock键（Numlock键）功能实现的问题

zjzcpj, 2022-10-09:
问题描述：目前正在修改98配列的键盘，需要实现NumLock键的功能。个人感觉和CapsLock键功能的实现是类似的，但是目前还没理解固件代码中是如何实现大小写锁定功能的，希望得到一些指导，主要问题如下：
1、如何实现NumLock功能？（或者说原本是怎么实现CapsLock功能的？）
2、固件代码‘hw_keyboard.h’文件中有一行与大小写相关的变量声明“ bool isCapsLocked = false;”，但未查找到用法，请问这个变量的作用是什么？
3、目前打算将右下角的3个LED灯用作Caps、Num、Pause状态指示灯，请问该如何获取目前的”Caps、Num、Pause“状态？

zhdjet, 2022-10-11:
1.Num_lock功能,程序有的,增加数字键盘配列后,Num_lock解锁后,就是方向键和功能键;
2.关于指示灯的问题,灯和按键连接到MCU的GPIO上,用按键控制灯的方式控制,至于锁定状态,我也在研究中;

peng-zhihui, 2022-10-11:
1. 各种Lock功能不是键盘实现的，而是电脑实现的，键盘只负责触发对应按键。（你可以在电脑上插两把键盘，按下一把的CapLock之后，另一把打字也是大写锁定的）
2. 那个变量就是判断是否按下Lock，而这个信息是电脑下发过来的。
3. Lock信息是USB接收到的，在CUSTOM_HID_OutEvent_FS函数里收到的第一个uint8_t的参数就是电脑下发的lock信息，每一位代表一个Caps、Num、Pause的状态（具体哪个位是哪个你可以自己测试一下），判断完了控制对应的灯就行了
4. 发送对应的Lock按键就用代码里的Press函数就行，比如keyboard.Press(HWKeyboard::CAP_LOCK)

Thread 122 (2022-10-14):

f103 printf重定向栈溢出问题

sytnocui, 2022-10-14:
最近调试的一个使用f103的小项目仿照了稚晖君的工具链与目录结构，但是发现同时使用printf重定向与freertos会直接flash爆满，就算减掉一些逻辑能运行起来，运行到printf还是会卡死。发现这个项目没有使用到freertos与printf，是有这方面的考虑吗，或者稚晖君有没有解决这个问题的方案呢

peng-zhihui, 2022-10-14:
F1很少有用RTOS的，flash和sram太小了，printf可以用，参考我cmakelist.txt里面的一些宏定义关掉一些编译器特性就行了

ewecan, 2024-02-28:
我在STM32CUBEIDE里c++环境下移植了u8g2，flash也爆了。估计也是编译器的锅，请问有朋友知道怎么修改编译器的特性吗

TheShallow, 2024-02-28:
这是来自小项的自动回复邮件。
 
邮件已收到

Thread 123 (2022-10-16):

进入BIOS设置界面

zh668, 2022-10-16:
1、无法进入BIOS设置界面。主板型号为：技嘉Z97-HD3
键盘功能都正常，F1、F2等按键测试正常。借助其它键盘进入BIOS后，瀚文键盘操作正常
2、开机时偶尔会卡在BIOS显示界面，只有拔掉瀚文键盘后正常。

zh668, 2022-10-17:
2、开机时偶尔会卡在BIOS显示界面，只有拔掉瀚文键盘后正常。
=========================================
解决方法：只有在按下按键时，才向电脑发送数据，解决该问题。
实际没有按键操作的时候，不需要一直发送按键数据给电脑。

zh668, 2022-10-17:
经测试，此方法可以连同无法进BIOS的问题也一起解决了

zhdjet, 2022-10-17:
知道是什么原因吗?B85的主板也遇到了这个现象,卡主板Logo,拨掉键盘后就马上正常启动了,经过我测试,原来是那个Hub芯片的问题,去年这个芯片,就一切正常了,搞不懂!

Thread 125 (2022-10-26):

LED灯珠控制问题

linhemin, 2022-10-26:
请问稚晖君，如果我想通过上位机更改LED的颜色，请问有什么方法吗

Closed 2022-10-29.

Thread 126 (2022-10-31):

6.6.1版本的cubeMX不再支持Clion开发

sytnocui, 2022-10-31:
最近手贱更新了一下cubeMx版本，发现已经无法打开之前 toolchain ide 是sw4stm32 的ioc文件了，也包括很多稚晖君项目的ioc文件，请问稚晖君这个有解决方案吗，还是说只能cubemx 降版本处理呢？
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

zhdjet, 2022-11-18:
clion是支持CubeMX6.6.1的，我现在就是用最新Clion和CubeMX的。

sytnocui, 2022-11-18:
>
请问您使用cubemx生成的工程是sw4stm32的吗，我现在打开cubemx已经无法生成sw4stm32的工程了，而且之前创建的sw4stm32的工程也全都打不开了

zhdjet, 2022-11-18:
stm32cubeIDE

zhdjet, 2022-11-18:
.ioc格式应该是CubeMX全版本兼容的；生成的代码工程文件格式是给编译IDE用的。

sytnocui, 2022-11-19:
> .ioc格式应该是CubeMX全版本兼容的；生成的代码工程文件格式是给编译IDE用的。

确实，我试了一下新建的cubemx工程如果选择toolchain是stm32cubeide的话，clion打开的，编译，单步调试确实都没有问题。
看来这样确实可以继续使用clion开发

但是有一个巨大的问题，您有没有试过使用6.6.1版本的cubemx打开过稚晖君之前的很多项目的ioc文件，稚晖君之前很多项目工具链选择都是sw4stm32，我尝试使用6.6.1版本的cubemx打开之前版本创建的工具链选择为sw4stm32的，都会报错打不开，就是最上面那个报错图，这意味着稚晖君很多项目的ioc文件我都看不了了，所以我现在又退回了6.5.0版本的cubemx。

今后我可能创建工程toolchain都会选择stm32cubeide，然后继续使用clion开发了，不知道稚晖君对这个问题怎么看？
@peng-zhihui

zhdjet, 2022-11-21:
其实是有一个非常简单的方法：
就是把旧版本的工程.ioc文件中的关于旧版本中关于版本号的数据全部改成新版本的；
再把sw4stm32改成stm32cubeide，保存后就可以用新版本的CubeMX打开了。
这个方法我一般不知诉别人的，哈哈。。。

zhdjet, 2022-11-21:
另外其实关于CubeMX的版本号不改，把sw4stm32改成stm32cubeide，也能打开；但是会有一个选择版本的提示框，随便点一个，就能打开。

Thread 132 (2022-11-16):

一个将键盘本体改成三模的想法

CC52242, 2022-11-16:
已知键盘无法实现无线的原因在于**睡眠后无法检测到按键按下**。
参考电路图，所有按键都由一个3.3v提供上拉，**那么只要将按键全部接到一个支持低电平或者下降沿触发中断的引脚上不就可以了**？
至于各个按键之间的串扰可以通过每个按键加一个二极管来解决。

合计最少只需要占用mcu的4个端口（三个原有的及一个中断触发位）。
**mcu进入睡眠前开启外部中断，被外部中断唤醒后即时关闭外部中断**。

CC52242, 2022-11-30:
公共引脚的连接位置在按键与165之间，二极管的连接位置在各按键的交汇点与按键之间，方向是从公共引脚至按键。公共引脚上有一个外部上拉（或内部上拉）

ourcabin0746, 2023-01-31:
至于各个按键之间的串扰可以通过每个按键加一个二极管来解决。
----------------------------------------------------------------------------
各个按键再增加二极管，就用行列扫描方式了，就没有大神这个设计优势了。

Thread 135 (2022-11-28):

关于瀚文键盘休眠后全键唤醒方案讨论以及HID键盘报文17字节切换标准8字节的请教

Wangzm007, 2022-11-28:
1.瀚文原连接方式想要唤醒休眠状态的话需要像Fn键一样,一个I/O连接一个按键上拉端,但是I/O口有限无法全键唤醒.
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
1.1所以我想到如下图两种连接方式来解决:方案①将原来按键的接地端统一接到单片机的一个I/O口上,该I/O口常态输出低电平,在进入休眠状态时重新初始化为输入状态,使能中断;在中断处理程序中退出休眠状态以及重新初始化为输出低电平状态.
1.2方案②由①变化而来,A口专门控制CMOS的连通与断开,B口中断输入判断:正常状态下用A控制CMOS连通,B口关闭中断使能;进入休眠时断开CMOS以及使能B中断输入使能.退出休眠时切换状态即可.
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
1.3上诉两种方案的不足之处在于休眠后第一次唤醒的按键可能不会输出到PC端(上述方案仅做讨论,未验证)
1.4写到这儿临时有个不成熟的想法,就是瀚文原方案中74HC165在单片机休眠时处于什么状态?按下某个按键时,74HC165是否会输出脉冲或电平转换到MCU,是的话能否将MCU相关的I/O口改为中断输入,正常状态初始化为SPI,休眠状态下初始化为中断输入以实现全键唤醒(瞎想的,我的编程水平无法验证)
-===================================================================
2.了解到一般HID键盘为了兼容在BIOS界面下使用是8字节报文(6键无冲),即第3字节:0x04是a,0x05是b,0x06是c ...等等;瀚文键盘17个字节按位表示(全键无冲),第三字节:0x10是a,0x20是b,0x40是c ... 等等.  但是看见有评论说瀚文键盘在bios界面下是可以使用的,所以想请教UP一下,瀚文是否可以切换这两种格式,让瀚文在有线连接进入系统时切换到1ms硬报文模式,其他状态下（如BIOS、无线蓝牙、2.4g连接时）切换到8字节报文兼容模式；如果可以的话应该在哪里切换,或者我想增加8字节报文的方式应该在程序哪个地方修改呢？

    期待up或者其他大佬有空的时候能够回复解答一下哦~主要是第2点报文问题，程序上我确实不太懂，买了最新版的00教你玩usb啃的也很艰难,万分感谢~
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

CC52242, 2022-11-30:
关于第一点的键盘唤醒，74hc165需要mcu为其提供时钟信号才能输出数据，所以mcu在休眠状态下无法通过读165来唤醒。
你可以看下我提的这个issue[https://github.com/peng-zhihui/HelloWord-Keyboard/issues/132](url).

关于第二点的usb报文，需要区分的是主机状态而不是连接方式。如果主机在UEFI或系统内，那就1kHZ；如果在Bios,那就8字节兼容。这大概只适用于采用usb连接时。2.4G以及BLE连接需要考虑的就不止usb报文的问题了。
对主机状态的区分可能需要通过区别主机发的控制传输来实现？
实在不行那就上电第一次配置usb设备时把自己设成8字节，进入系统后软重启重配置为1kHZ

我自己也是正在学习，意见中可能会有不少荒唐的地方，还请赐教指正

xingrz, 2022-12-19:
我觉得楼主这个想法很合理，应该是可以实现的。甚至更进一步，我觉得可以加一个 MOS 管休眠状态下把 74HC165 的 VCC 全断掉（不过这个得测一下 74HC165 的电流多大，如果确实小得忽略不计，那就没必要了）。

> 就是瀚文原方案中74HC165在单片机休眠时处于什么状态?按下某个按键时,74HC165是否会输出脉冲或电平转换到MCU

165 是不会主动输出电平的，得靠 MCU 的时钟信号驱动它。

BrianLChen, 2023-01-09:
165再无时钟信号的情况下不会输出，但是应该是有输入的吧。如果从休眠状态回到正常状态的时间足够短，是不是165依然可以检测到按键？也就是说可能并不会吞掉唤醒按键。
第二种方法做唤醒应该是没有问题的，B口做为输入，自身下拉，高电平唤醒。

Mexico-zyy-lost, 2023-01-11:
usb的报文协议在哪可以看？

ourcabin0746, 2023-01-31:
我也一直在思考休眠的问题，请问大家有可用的思路和方法了吗？
在USB可以考虑不用休眠，但是如果瀚文这套方案用在BLE，2.4G下，麻烦就比较多。

Xing-C, 2024-03-24:
有哪位大佬有进展了吗？  迟迟未动手的原因之一就是想有个2.4G...

BrianLChen, 2024-03-26:
> 有哪位大佬有进展了吗？ 迟迟未动手的原因之一就是想有个2.4G...

用nrf52840写了一个，可以在我仓库里看到。但是有一些bug，一直没时间修

lijunru-hub, 2024-06-26:
用 esp32s3 做了一个键盘 https://oshwhub.com/esp-college/esp-keyboard，全按键唤醒，低功耗 BLE等

TheShallow, 2024-06-26:
这是来自小项的自动回复邮件。
 
邮件已收到

lijunru-hub, 2024-06-26:
USB 的全键无冲和六键的上报逻辑是。

如果你按下的按键没超过 6 个，就按六键的接口上报，超过就按全键的接口上报。
在 BIOS 里面因为不会去识别 USB HID 报文，所以键盘里面默认有一个标准六键上报的就行了，只要你不按太多个键，BIOS 里面就是能正常用的

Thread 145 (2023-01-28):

USB Config Descriptor 中的问题

BrianLChen, 2023-01-28:
在文件 “usbd_customhid.c” 中，146，205和264行。这把键盘的设计应该是使用USB总线供电，而非自供电，而且键盘带有远程唤醒。为什么这里的值是0xC0 (1100 0000)而不是0xA0 (1010 0000)。

根据定义，D6为供电方式标识，0为总线供电，1为自供电。D5为远程唤醒标识符，1为支持远程唤醒。

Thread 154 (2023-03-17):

更新墨水屏图片失败！驱动已安装完成

CrazyzhouLL, 2023-03-17:
使用software工具更新墨水屏图片失败！驱动已安装完成，
求助怎么解决。。。
报错截图
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
设备管理界面截图
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

remador, 2023-04-12:
Estou a 4,5 meses nessa tortura.
Nem tenho palavras pra agradecer,
Muito obrigado!
@Mitodacaverna

TheShallow, 2023-04-12:
这是来自小项的自动回复邮件。
 
邮件已收到

remador, 2023-04-12:
Muito obrigado!
Estou exausto!
@remador

remador, 2023-04-12:
Muito obrigado!
Estou exausto.
@remador

XBMAX, 2024-04-14:
I just built my keyboard and I'm a bit confused how to get the e-ink screen working? My screen isn't working out of the box. I have downloaded the actual file and the first test image but it says failed to connect to the device. I do have Zadig and the STM program - can someone please assist me in what I need to do to get this function? Also is there a .json file to use with VIA?

Thank you!

TheShallow, 2024-04-14:
这是来自小项的自动回复邮件。
 
邮件已收到

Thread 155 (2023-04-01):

关于PCB加入优联主控实现无线多设备切换及拓展部分实现音频软件推子的功能

XVaj, 2023-04-01:
稚晖菌大佬好，我是一名混音师，很久之前就看到了瀚文键盘的项目，之前视频里有提及音乐制作模块不知道现在是否有实现？作为一名混音师，我希望左侧的拓展模块能变成4个推子，可以连接到音乐制作软件实现对软件调音台的控制，最终效果其实偏向您视频中的直播模块的样式，另外，是否有可能加入罗技优联的K375S等优联主控，实现多设备无线切换使用？如果可以该怎么实现呢？另外还需要小数字键盘区，最终组成100配列或者96配列，电路及程序纯小白，所以多有打扰还请见谅

dghcz, 2024-03-17:
同问

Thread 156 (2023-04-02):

MUTE，VOLUME_UP，VOLUME_DOWN这类功能键不起作用

joye-wang, 2023-04-02:
请教一下，为什么 MUTE，VOLUME_UP，VOLUME_DOWN这类按键不起作用呢？
普通按键都是可以映射的，类似A-Z,  F1-F12都是可以的。但是从键盘枚举的某一个位置开始之后所有的按键都没用了.
请看代码的注释：
```
enum KeyCode_t {
	/*------------------------- HID report data -------------------------*/
	LEFT_CTRL = -8,
	LEFT_SHIFT = -7,
	LEFT_ALT = -6,
	LEFT_GUI = -5,
	RIGHT_CTRL = -4,
	RIGHT_SHIFT = -3,
	RIGHT_ALT = -2,
	RIGHT_GUI = -1,

	RESERVED = 0,
	ERROR_ROLL_OVER,
	POST_FAIL,
	ERROR_UNDEFINED,
	A,
	B,
	C,
	D,
	E,
	F,
	G,
	H,
	I,
	J,
	K,
	L,
	M,
	N,
	O,
	P,
	Q,
	R,
	S,
	T,
	U,
	V,
	W,
	X,
	Y,
	Z,
	NUM_1/*1!*/,
	NUM_2/*2@*/,
	NUM_3/*3#*/,
	NUM_4/*4$*/,
	NUM_5/*5%*/,
	NUM_6/*6^*/,
	NUM_7/*7&*/,
	NUM_8/*8**/,
	NUM_9/*9(*/,
	NUM_0/*0)*/,
	ENTER,
	ESC,
	BACKSPACE,
	TAB,
	SPACE,
	MINUS/*-_*/,
	EQUAL/*=+*/,
	LEFT_U_BRACE/*[{*/,
	RIGHT_U_BRACE/*]}*/,
	BACKSLASH/*\|*/,
	NONE_US/**/,
	SEMI_COLON/*;:*/,
	QUOTE/*'"*/,
	GRAVE_ACCENT/*`~*/,
	COMMA/*,<*/,
	PERIOD/*.>*/,
	SLASH/*/?*/,
	CAP_LOCK,
	F1,
	F2,
	F3,
	F4,
	F5,
	F6,
	F7,
	F8,
	F9,
	F10,
	F11,
	F12,
	PRINT,
	SCROLL_LOCK,
	PAUSE,
	INSERT,
	HOME,
	PAGE_UP,
	DELETE,
	END,
	PAGE_DOWN,
	RIGHT_ARROW,
	LEFT_ARROW,
	DOWN_ARROW,
	UP_ARROW,
	PAD_NUM_LOCK,
	PAD_SLASH,
	PAD_ASTERISK,
	PAD_MINUS,
	PAD_PLUS,
	PAD_ENTER,
	PAD_NUM_1,
	PAD_NUM_2,
	PAD_NUM_3,
	PAD_NUM_4,
	PAD_NUM_5,
	PAD_NUM_6,
	PAD_NUM_7,
	PAD_NUM_8,
	PAD_NUM_9,
	PAD_NUM_0,
	PAD_PERIOD,
	NONUS_BACKSLASH, // 大概从这个位置开始，下面的按键都没用
	APPLICATION,
	POWER,
	PAD_EQUAL,
	F13,
	F14,
	F15,
	F16,
	F17,
	F18,
	F19,
	F20,
	F21,
	F22,
	F23,
	F24,
	EXECUTE,
	HELP,
	MENU,
	SELECT,
	STOP,
	AGAIN,
	UNDO,
	CUT,
	COPY,
	PASTE,
	FIND,
	MUTE,
	VOLUME_UP,
	VOLUME_DOWN,
	FN = 1000
/*------------------------- HID report data -------------------------*/
};

```

yr785444662, 2023-04-17:
同上，媒体功能按键无效

BrianLChen, 2023-05-14:
Windows 好像 HID Usage ID 好像到101就没有了，想要实现音量控制需要使用 Consumer Page （0x0c）中的 Volume Control 才可以实现。我也在尝试中。

BrianLChen, 2023-06-18:
可以在原先的report desc中加入一个新的collection， Report ID = 2；
report buffer 的第1个字节用于声明report ID（我记得我在代码里看到有这部分的了）。

        /* Volume */ \
        0x05, 0x0c,  /* Usage Page (Consumer) */ \
        0x09, 0x01,  /* USAGE Consumer Control */ \
        0xa1, 0x01,  /* COLLECTION (Application)                       */ \
        0x85, 0x02,  /* Report ID = 2 */ \
        0x05, 0x0c,  /* Usage Page (Consumer) */ \
        0x15, 0x00,  /* logic min */ \
        0x25, 0x01,  /* logic max */ \
        0x75, 0x01,  /* rep size 1 */ \
        0x95, 0x08,  /* rep count (07) */ \
        0x09, 0xe9,  /* usage volume increase */ \
        0x09, 0xea,  /* usage volume decrease */ \
        0x09, 0xe2,  /* usage mute */ \
        0x09, 0xcd,  /* uasge play/pause */ \
        0x09, 0xb5,  /* uasge next track */ \
        0x09, 0xb6,  /* uasge Previous track */ \
        0x09, 0xb7,  /* uasge stop */ \
        0x0a, 0x92, 0x01, /* Open Application: Calculator */ \
        0x81, 0x02,  /* output */ \
        \
        0xc0,                           /* END_COLLECTION                                 */\

需要对原本代码中的remap的结构进行修改，对 report ID = 1 和 report ID = 2 的两个 report buff 进行分开计算。优先对 report ID = 1 的report buffer进行报表（考虑到键盘时更加重要的功能）。当 report ID=1 所对应的 report buffer 没有改动时，对report ID = 2 的 report buffer 进行报表，所以需要两个不同的 report buffer。

所以需要额外的判断，判断2个report buffer 是否较之前有所变化。

两个不同report ID只能进行分开的报表。而键盘的usage type时keyboard，音量控制的usage type 时consumer control， 不同的usage type也不能放在同一个collection中。

好像还有一种方法就是重新声明一个USB HID 设备，使用不同的endpoint。目前并没有对这个方法进行深入的研究

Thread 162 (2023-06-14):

LED灯闪烁问题和TYPE-C上电出现啸叫声

ideal1213123, 2023-06-14:
稚晖军你好！我的上电后led灯闪烁频率很快，按住UI键后会缓慢闪烁，松开后继续快闪。type-c模块有电流的啸叫声，略有发烫，按住UI键后zh发烫上升，没有接电池。单独给TYPE-C供电没有电流的啸叫声也不会发烫。led灯珠用的是0628带IC反贴的。

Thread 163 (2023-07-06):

Type-C电源供电和发热问题

ideal1213123, 2023-07-06:
单独 TYPE-C 供电，主控板 RGB 灯珠后半部分会闪烁。加上电池同时供电后 RGB 灯珠正常发光，但 Type-C PCB 板严重发热，无扩展模块。请问这正常吗

TheShallow, 2023-07-06:
这是来自小项的自动回复邮件。
 
邮件已收到

PelloBravo, 2023-07-07:
这个方案应该是不能用typec直连的，应该用usb2.0的typeA接口转typec。
我猜测是因为加入了上拉电阻的缘故，导致usb3的typec输出12v电压导致的电路板发热。

ideal1213123, 2023-07-16:
>

所以加上电池供电后发热是可以用的，不会烧掉。对吧。

PelloBravo, 2023-07-16:
难说，理论上是可以，因为原设计MCU是信号线供电的。不过你typec和电池同时连是怎么连的？串联还是并联？

xingrz, 2023-07-31:
> 这个方案应该是不能用typec直连的，应该用usb2.0的typeA接口转typec。 我猜测是因为加入了上拉电阻的缘故，导致usb3的typec输出12v电压导致的电路板发热。

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

我特意去重新看了眼原理图，USB-C 口只有 CC1 和 CC2 分别 5.1K 下拉，没有你所说的上拉。这是符合 USB-C 的规范的。

另外，无论 USB 2.0 还是 3.0，无论 Type-A 还是 Type-C，只要你没有专门的芯片去做 USB-PD 握手，VBUS 上只会是 5V。并不会像你所说加了电阻就变成了 3.0、3.0 就是 12V 的情况。

PelloBravo, 2023-08-01:
啊对，是我接线错了。。。我加了一个ph2.0的端口接买来的typec口调试，那个typec口是din dout+cc线的不是+uart的。。。
不过我接usb3.0后测出的LED电压确实是12v，可能是我的线自带PD芯片？

xingrz, 2023-08-01:
> 我加了一个ph2.0的端口接买来的typec口调试，那个typec口是din dout+cc线的不是+uart的

没看懂…感觉你把不同的东西混为一谈了。USB 2.0 就 VBUS/D-/D+/GND 四根线，哪怕是 USB 3.0 多了四对 TX/RX 也是 USB 信号，并不是 UART，也不叫 DIN DOUT。

我猜，你说的 `买来的typec口` 并不是单纯的 USB Type-C 连接器，而是别人做好的某种转接板？

PelloBravo, 2023-08-01:
不是，是6pin的ph2.0转typec，6pin其中是d+d- cc1cc2 gnd vbus，要想正常使用得是d+d- tx rx gnd vbus。
typec的d+d-就是2.0的信号

PelloBravo, 2023-08-01:
我看了下原理图，uart是控制那个dynamic模块的，实际上typec接口只接了4根线。。

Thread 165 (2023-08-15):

立创开源的键盘工程是不是没了

wolter-H, 2023-08-15:
立创开源的键盘工程好像没人，有没有大佬保存发一下

TheShallow, 2023-08-15:
这是来自小项的自动回复邮件。
 
邮件已收到

esmusssein-zhao, 2023-08-20:
好像确实没了，兄弟有找到吗？可以分享一下吗？

Picucu, 2023-08-20:
真的没有了，有人有吗？

conveylove9, 2023-08-24:
确实没了，有兄弟分享吗

Aoxiang5887, 2023-08-25:
同求一份

abeitian, 2023-08-27:
同求更新！！！Hardware链接完全失效

jh1Y, 2023-08-27:
同求一份

Mexico-zyy-lost, 2023-08-28:
有没有大佬发我一份，1130349616@qq.com
谢谢！

jensentsts, 2023-10-05:
Hardware里面有写的，这里我贴一个：[https://oshwhub.com/pengzhihui/b11afae464c54a3e8d0f77e1f92dc7b7](https://oshwhub.com/pengzhihui/b11afae464c54a3e8d0f77e1f92dc7b7)

canuckkat, 2023-11-12:
I can't make a new account on oshwhub (outside of China - not receiving verification code to register), so it would be helpful if someone could upload the files somewhere more accessible globally. Thanks!

TheShallow, 2023-11-12:
这是来自小项的自动回复邮件。
 
邮件已收到

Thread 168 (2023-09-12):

Pcb files again

KO-07, 2023-09-12:
Hi, I just wanted to know if there are any pcb files to this project, or is there a way to convert the pdf schematics into the herber file format?

Thanks.

TheShallow, 2023-09-12:
这是来自小项的自动回复邮件。
 
邮件已收到

KO-07, 2023-09-12:
I don't speak Chinese my friend :(

KO-07, 2023-09-12:
Is there a link to where the PCBs are for this project?

realhistory, 2023-09-21:
> Is there a link to where the PCBs are for this project?
is here : https://oshwhub.com/pengzhihui/b11afae464c54a3e8d0f77e1f92dc7b7

realhistory, 2023-09-21:
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

sure,please leave your email, i will send to you files

KO-07, 2023-09-21:
Sure thing, I will attach my email, but before that, if it's ok, I just wanted to know if there is any other way to attach the files to github?

KO-07, 2023-09-21:
Anyway to send besides email if possible? If not then I'll give you the email address.

maghdzany, 2024-03-23:
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

Can you also send me gerber files? This is my email maghzml@gmail.com I can't login with wechat :')

KO-07, 2024-03-23:
Hi, I would also like the gerber files/pcb files for this project. If anyone could send me the files to my email, that would be much appreciated.
KO7.Fzn@Gmail.com

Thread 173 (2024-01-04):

关于按键滤波方案的一个想法

Huffer342-WSH, 2024-01-04:
- 假如按键输入长时间没有发生变化，突然电平发生了改变，即使之后会有抖动，也可以认为按键状态已经发生变化，而不用在延迟一次或者多次扫描结果在做判断。
- 假如按键输入前一段时间不稳定，那就按照普通的方案等按键稳定。

假如键盘没有按下或者松开，电平无缘无故发生变化，那肯定是轴坏了或者键盘摔地上了。

N：认为键盘长时间没有变化的门限，比如按下按键触发时间一般都有几十毫秒，N=50差不多
M:  M次扫描结果相同，认为按键稳定。客制化轴体水平参差不齐，这个M不好说，段落轴由于弹片震动，更加不稳定。
状态A：前N次扫描电平无抖动
状态B：前N次扫描电平发生变化
电平L，扫描输入K，上一次扫描输入Kp
状态A———电平不变 L==Kp==K————> 状态A
状态A———电平发生变化 L==Kp!=K————> 状态B  直接修改电平状态L=K
状态B———电平发生变化 Kp!=K————> 状态B  cnt=0
状态B———电平不发生变化 Kp==K,cnt<N————> 状态B  cnt++；cnt>=M : L=K ;
状态B———电平不发生变化 Kp==K,cnt>=N————> 状态A

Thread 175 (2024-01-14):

无法理解keymap和keyboard.remap

ThanatosSui, 2024-01-14:
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
第一个是稚辉君的最新code。第二个是我在嘉立创看到的。
我找了半天也没看到稚辉君的code里有remap这个package。求帮助。
谢谢

1354074524, 2024-06-03:
不知道我理解的对不对，你是想要找到实现remap的代码吗，如果是的话，它在hw_keyboard.cpp中

ThanatosSui, 2024-06-03:
> 不知道我理解的对不对，你是想要找到实现remap的代码吗，如果是的话，它在hw_keyboard.cpp中

感谢，我找到了，但是现在问题是，稚晖君的code只有两层remap，用的是FN键切换，我自己再尝试做的是4层的remap，现在还没搞明白应该怎么做。因为怕code打错就导致无法更新系统。

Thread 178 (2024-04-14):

E-Ink doesn't turn on - .json file for VIA?

XBMAX, 2024-04-14:
I just built my keyboard and I'm a bit confused how to get the e-ink screen working? My screen isn't working out of the box. I have downloaded the actual file and the first test image but it says failed to connect to the device. I do have Zadig and the STM program - can someone please assist me in what I need to do to get this function? Also is there a .json file to use with VIA?

Thank you!

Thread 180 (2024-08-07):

键盘固件中的HID报表描述符在哪

EchoJames, 2024-08-07:
只找到一个只有2字节的HID报表描述符
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

TheShallow, 2024-08-07:
这是来自小项的自动回复邮件。
 
邮件已收到

MingJerry, 2024-08-23:
定义在这个文件usbd_custom_hid_if.c文件。基于STM32的HID设备开发，通过((USBD_CUSTOM_HID_ItfTypeDef *)pdev->pUserData)->pReport调用。

TheShallow, 2024-08-23:
这是来自小项的自动回复邮件。
 
邮件已收到

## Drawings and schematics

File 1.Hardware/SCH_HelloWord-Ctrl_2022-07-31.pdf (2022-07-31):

POWER | E-INK
PORT | BUTTON | RGB

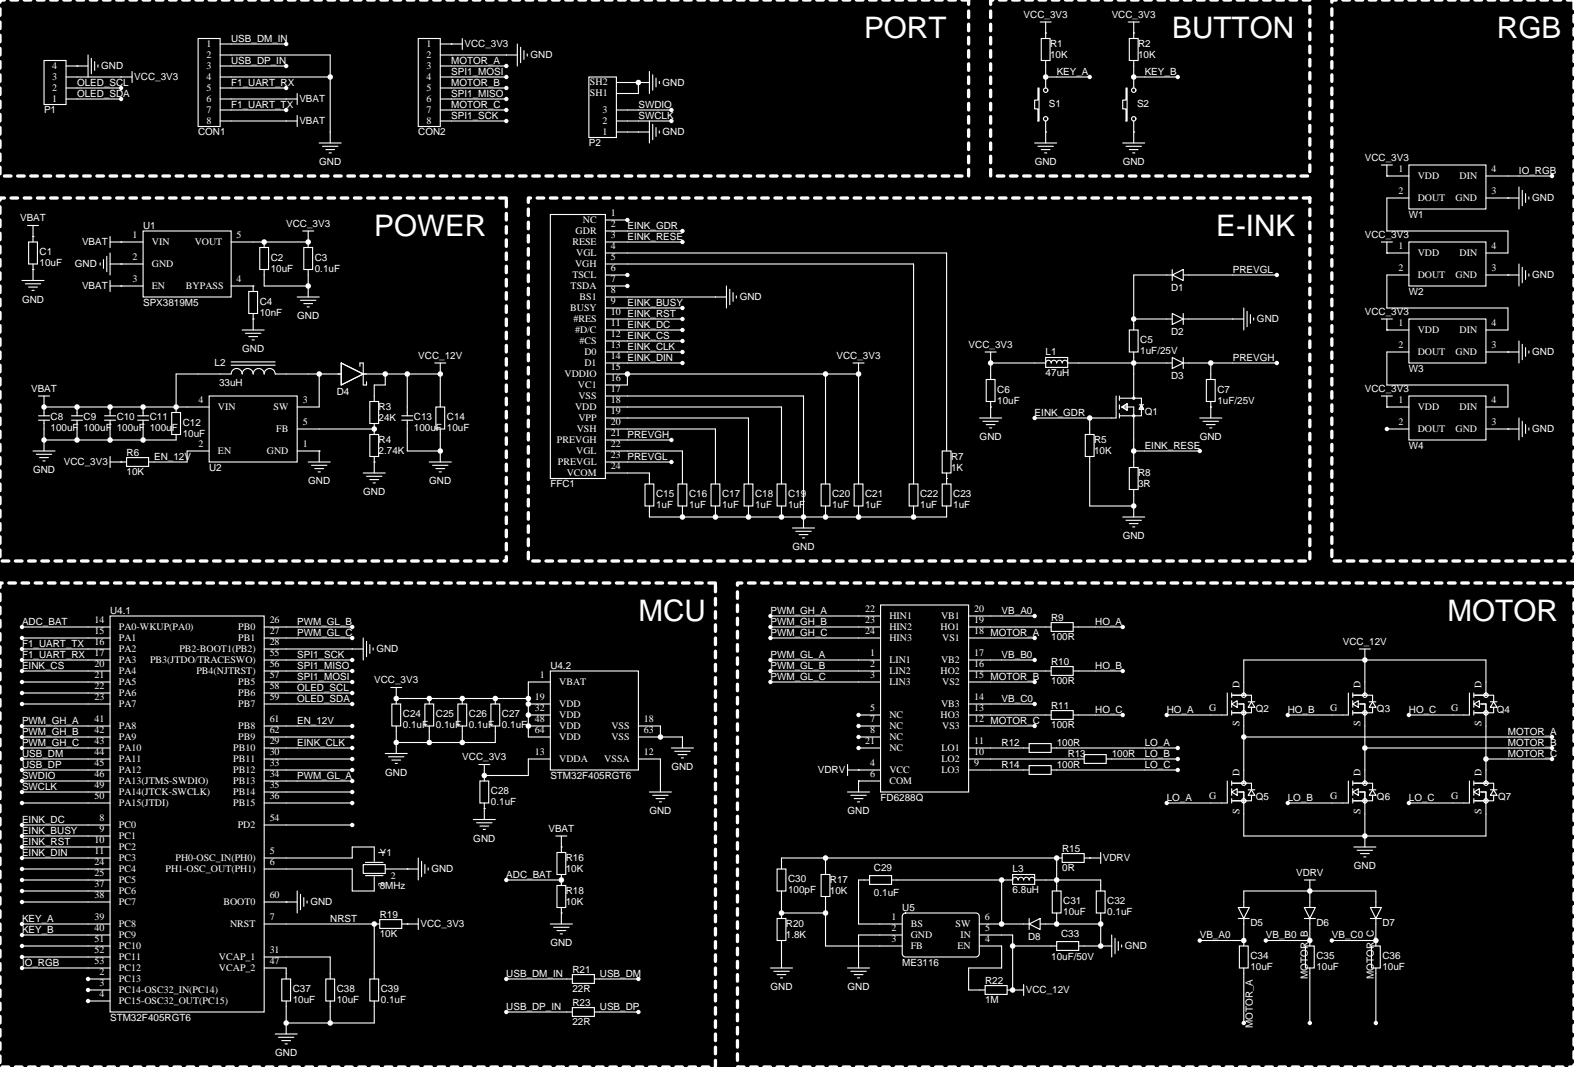
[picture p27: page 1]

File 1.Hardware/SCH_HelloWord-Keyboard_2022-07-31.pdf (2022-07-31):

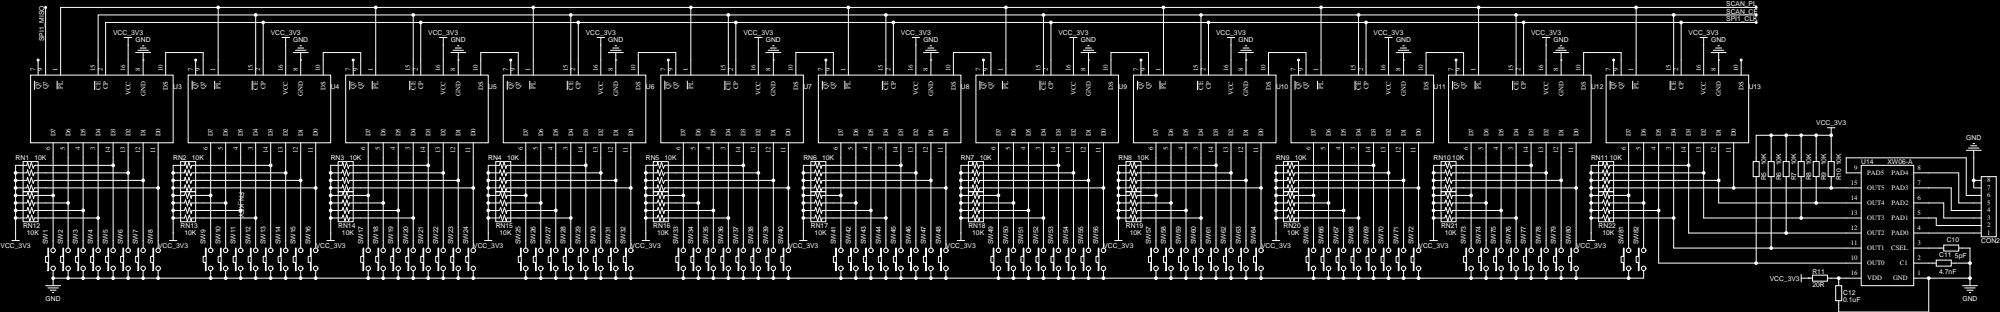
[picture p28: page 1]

MCU | POWER & CONN

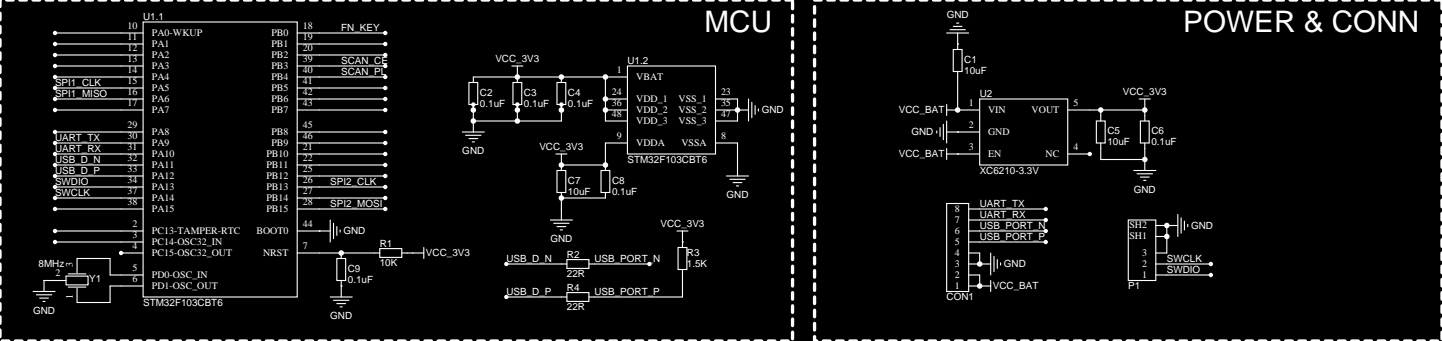
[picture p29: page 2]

VDD; DOUT; GND; DIN; VCC_BAT; RGB_KEY; SPI2_MOSI
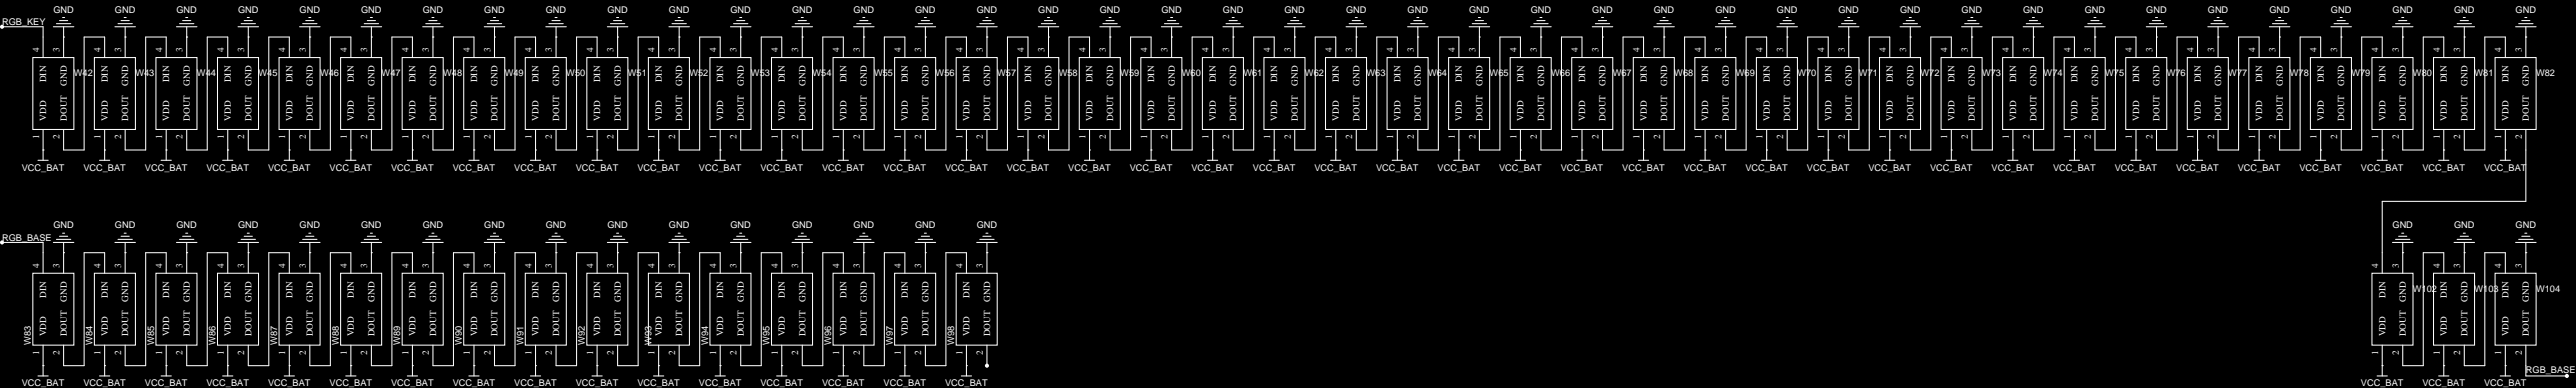
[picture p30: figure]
VDD; DOUT; GND; DIN; VCC_BAT; RGB_KEY; RGB_BASE

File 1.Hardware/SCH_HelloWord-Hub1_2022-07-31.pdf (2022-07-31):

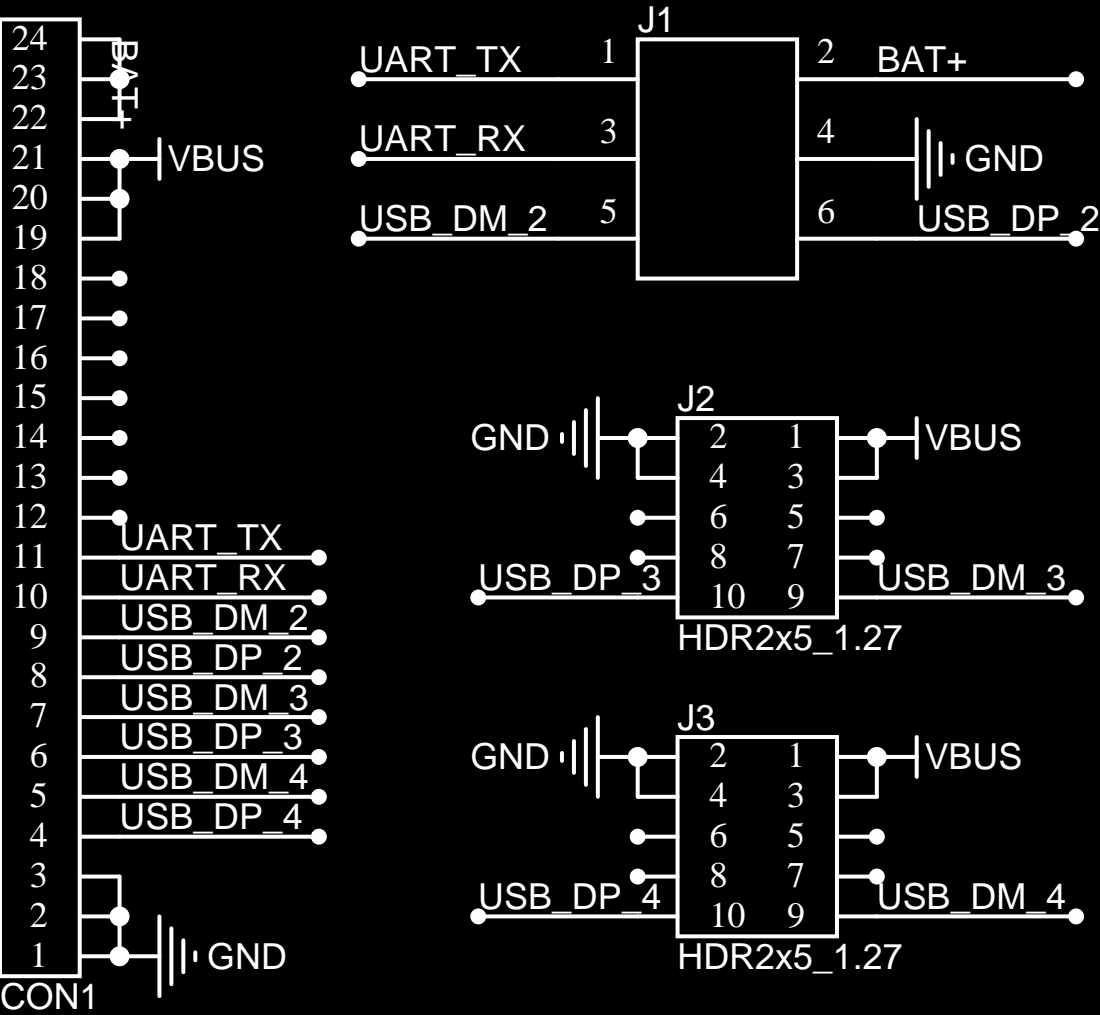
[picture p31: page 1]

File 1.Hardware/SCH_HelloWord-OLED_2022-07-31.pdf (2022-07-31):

# OLED

28 NC 1

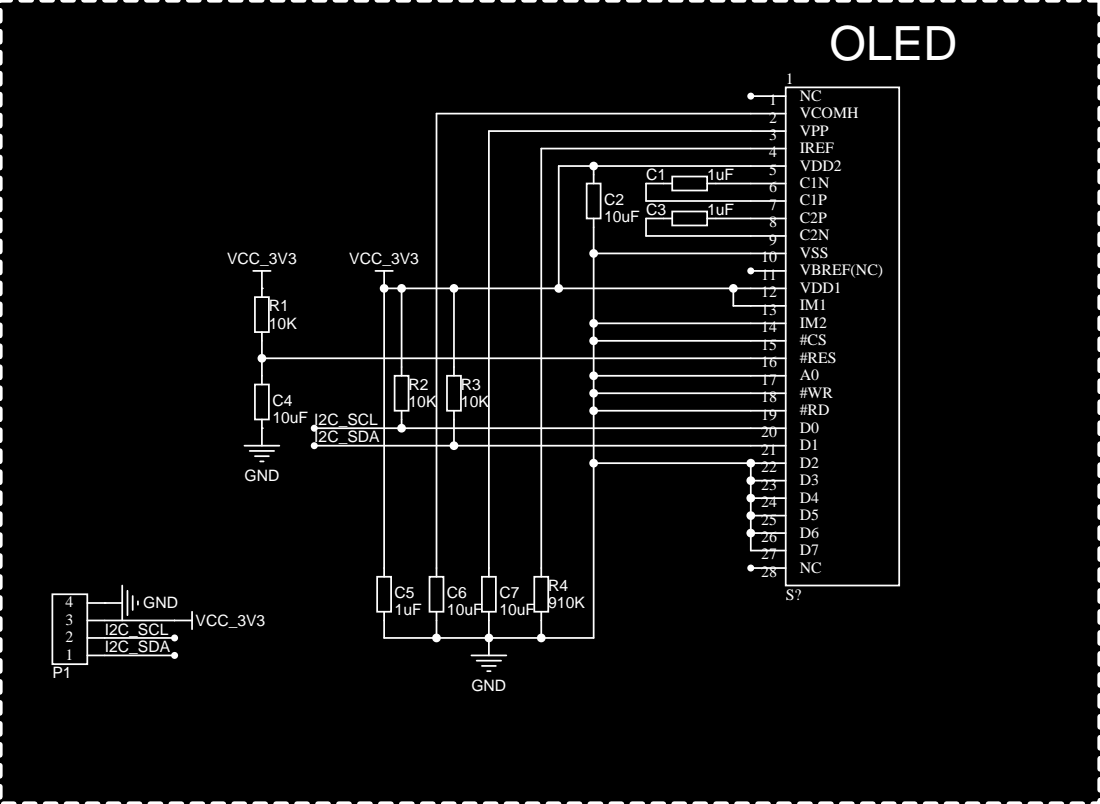
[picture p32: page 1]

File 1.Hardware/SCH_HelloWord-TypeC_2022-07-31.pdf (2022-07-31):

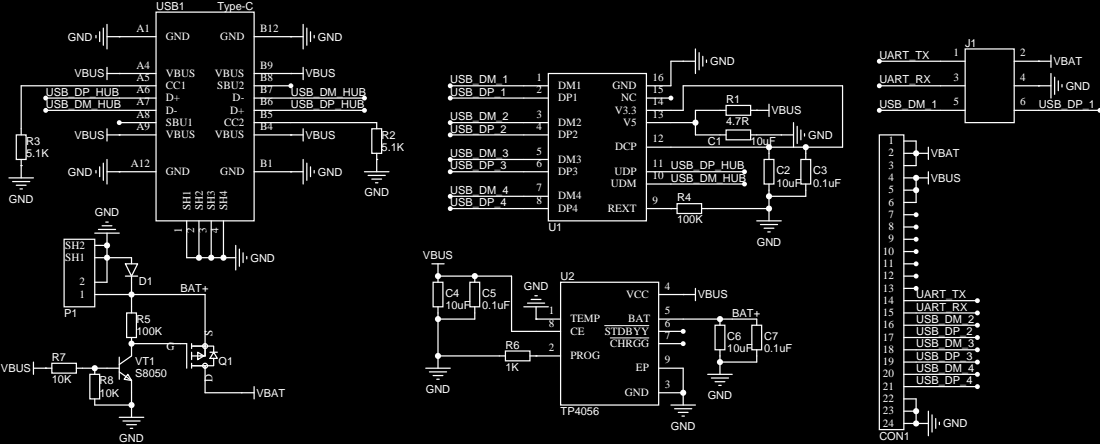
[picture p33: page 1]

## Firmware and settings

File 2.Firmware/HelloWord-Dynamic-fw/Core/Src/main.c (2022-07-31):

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
/* Includes ------------------------------------------------------------------*/
#include "main.h"
#include "cmsis_os.h"
#include "adc.h"
#include "dma.h"
#include "i2c.h"
#include "spi.h"
#include "tim.h"
#include "usart.h"
#include "usb_device.h"
#include "gpio.h"


/* USER CODE BEGIN PV */
uint64_t serialNumber;
char serialNumberStr[13];
/* USER CODE END PV */

void SystemClock_Config(void);
void MX_FREERTOS_Init(void);
/**
  * @brief  The application entry point.
  * @retval int
  */
int main(void)
{
  /* USER CODE BEGIN 1 */
HAL_RCC_DeInit();
    // This procedure of building a USB serial number should be identical
    // to the way the STM's built-in USB bootloader does it. This means
    // that the device will have the same serial number in normal and DFU mode.
    uint32_t uuid0 = *(uint32_t *) (UID_BASE + 0);
    uint32_t uuid1 = *(uint32_t *) (UID_BASE + 4);
    uint32_t uuid2 = *(uint32_t *) (UID_BASE + 8);
    uint32_t uuid_mixed_part = uuid0 + uuid2;
    serialNumber = ((uint64_t) uuid_mixed_part << 16) | (uint64_t) (uuid1 >> 16);

    uint64_t val = serialNumber;
    for (size_t i = 0; i < 12; ++i)
    {
        serialNumberStr[i] = "0123456789ABCDEF"[(val >> (48 - 4)) & 0xf];
        val <<= 4;
    }
    serialNumberStr[12] = 0;

  /* USER CODE END 1 */

  /* MCU Configuration--------------------------------------------------------*/

  /* Reset of all peripherals, Initializes the Flash interface and the Systick. */
  HAL_Init();

  /* USER CODE BEGIN Init */
    HAL_RCC_DeInit();

  /* USER CODE END Init */

  /* Configure the system clock */
  SystemClock_Config();

  /* Initialize all configured peripherals */
  MX_GPIO_Init();
  MX_DMA_Init();
  MX_I2C1_Init();
  MX_SPI1_Init();
  MX_ADC1_Init();
  MX_TIM1_Init();
  MX_USART2_UART_Init();
  MX_TIM9_Init();
  MX_SPI2_Init();
  MX_SPI3_Init();
  /* Init scheduler */
  osKernelInitialize();  /* Call init function for freertos objects (in freertos.c) */
  MX_FREERTOS_Init();
  /* Start scheduler */
  osKernelStart();

  /* We should never get here as control is now taken by the scheduler */
  /* Infinite loop */
  /* USER CODE BEGIN WHILE */

    while (1)
    {
    /* USER CODE END WHILE */

    /* USER CODE BEGIN 3 */
    }
  /* USER CODE END 3 */
}

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
/* USER CODE BEGIN 4 */
void OnTimerCallback(TIM_TypeDef *timInstance);
/* USER CODE END 4 */

 /**
  * @brief  Period elapsed callback in non blocking mode
  * @note   This function is called  when TIM6 interrupt took place, inside
  * HAL_TIM_IRQHandler(). It makes a direct call to HAL_IncTick() to increment
  * a global variable "uwTick" used as application time base.
  * @param  htim : TIM handle
  * @retval None
  */
void HAL_TIM_PeriodElapsedCallback(TIM_HandleTypeDef *htim)
{
  if (htim->Instance == TIM6) {
    HAL_IncTick();
  }
  /* USER CODE BEGIN Callback 1 */
  else
  {
      OnTimerCallback(htim->Instance);
  }
  /* USER CODE END Callback 1 */
}

/**
  * @brief  This function is executed in case of error occurrence.
  * @retval None
  */
void Error_Handler(void)
{
  /* USER CODE BEGIN Error_Handler_Debug */
    /* User can add his own implementation to report the HAL error return state */
    __disable_irq();
    while (1)
    {
    }
  /* USER CODE END Error_Handler_Debug */
}

#ifdef  USE_FULL_ASSERT
/**
  * @brief  Reports the name of the source file and the source line number
  *         where the assert_param error has occurred.
  * @param  file: pointer to the source file name
  * @param  line: assert_param error line source number
  * @retval None
  */
void assert_failed(uint8_t *file, uint32_t line)
{
  /* USER CODE BEGIN 6 */
  /* User can add his own implementation to report the file name and line number,
     ex: printf("Wrong parameters value: file %s on line %d\r\n", file, line) */
  /* USER CODE END 6 */
}
#endif /* USE_FULL_ASSERT */

/************************ (C) COPYRIGHT STMicroelectronics *****END OF FILE****/

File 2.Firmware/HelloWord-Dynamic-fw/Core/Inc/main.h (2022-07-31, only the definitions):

#define EINK_DC_Pin GPIO_PIN_0
#define EINK_DC_GPIO_Port GPIOC
#define EINK_BUSY_Pin GPIO_PIN_1
#define EINK_BUSY_GPIO_Port GPIOC
#define EINK_RST_Pin GPIO_PIN_2
#define EINK_RST_GPIO_Port GPIOC
#define EINK_CS_Pin GPIO_PIN_4
#define EINK_CS_GPIO_Port GPIOA
#define M0_PWM_BL_Pin GPIO_PIN_0
#define M0_PWM_BL_GPIO_Port GPIOB
#define M0_PWM_CL_Pin GPIO_PIN_1
#define M0_PWM_CL_GPIO_Port GPIOB
#define M0_PWM_AL_Pin GPIO_PIN_13
#define M0_PWM_AL_GPIO_Port GPIOB
#define KEY_A_Pin GPIO_PIN_8
#define KEY_A_GPIO_Port GPIOC
#define KEY_B_Pin GPIO_PIN_9
#define KEY_B_GPIO_Port GPIOC
#define M0_PWM_AH_Pin GPIO_PIN_8
#define M0_PWM_AH_GPIO_Port GPIOA
#define M0_PWM_BH_Pin GPIO_PIN_9
#define M0_PWM_BH_GPIO_Port GPIOA
#define M0_PWM_CH_Pin GPIO_PIN_10
#define M0_PWM_CH_GPIO_Port GPIOA
#define M0_CS_Pin GPIO_PIN_2
#define M0_CS_GPIO_Port GPIOD
#define VMOTOR_EN_Pin GPIO_PIN_8
#define VMOTOR_EN_GPIO_Port GPIOB

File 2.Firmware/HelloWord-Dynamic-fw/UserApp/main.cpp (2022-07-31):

#include "common_inc.h"
#include "Platform/Sensor/Encoder/encoder.h"
#include "Platform/Driver/driver.h"
#include "Ctrl/Motor/motor.h"
#include "eink_290_bw.h"
#include "rgb_light.h"
#include "Ctrl/Motor/knob.h"
#include "U8g2lib.hpp"


/* User Variables ---------------------------------------------------------*/
BoardConfig_t boardConfig;
SSD1306 oled(&hi2c1);
Eink290BW eink;
Timer timerCtrlLoop(&htim7, 5000);
Encoder encoder(&hspi1);
Driver driver(12);
Motor motor = Motor(7);
RGB rgb(&hspi3);
KnobSimulator knob;


/* Thread Definitions -----------------------------------------------------*/
osThreadId_t ctrlLoopTaskHandle;
void ThreadCtrlLoop(void* argument)
{
    motor.AttachDriver(&driver);
    motor.AttachEncoder(&encoder);
    knob.Init(&motor);
    knob.SetEnable(true);
    knob.SetMode(KnobSimulator::MODE_DAMPED);

    for (;;)
    {
        // Suspended here until got Notification.
        ulTaskNotifyTake(pdTRUE, portMAX_DELAY);

        knob.Tick();
    }
}

osThreadId_t oledTaskHandle;
void ThreadOledUpdate(void* argument)
{
    oled.Init();
    eink.Init();

    for (;;)
    {
        //OLED update
        oled.Clear();
        oled.SetDrawColor(1);
        oled.SetCursor(0, 0);
        oled.DrawUTF8(0, 10, "hello");
        oled.SendBuffer();


        //RGB update
        for (uint8_t i = 0; i < RGB::LED_NUMBER; i++)
            rgb.SetRgbBuffer(i, RGB::Color_t{128, 20, 0});

        rgb.SyncLights();
    }
}

osThreadId_t peripheralTaskHandle;
void ThreadGpioUpdate(void* argument)
{
    int mode = 0;

    for (;;)
    {
        if (HAL_GPIO_ReadPin(KEY_A_GPIO_Port, KEY_A_Pin) == GPIO_PIN_RESET)
        {
            while (HAL_GPIO_ReadPin(KEY_A_GPIO_Port, KEY_A_Pin) == GPIO_PIN_RESET);
            mode++;
            if (mode > 5)mode = 0;
            knob.SetMode(static_cast<KnobSimulator::Mode_t>(mode));
        }
        if (HAL_GPIO_ReadPin(KEY_B_GPIO_Port, KEY_B_Pin) == GPIO_PIN_RESET)
        {
            while (HAL_GPIO_ReadPin(KEY_B_GPIO_Port, KEY_B_Pin) == GPIO_PIN_RESET);
            mode--;
            if (mode < 0)mode = 5;
            knob.SetMode(static_cast<KnobSimulator::Mode_t>(mode));
        }

        osDelay(20);
    }
}


/* Timer Callbacks -------------------------------------------------------*/
void OnTimerCallback()
{
    BaseType_t xHigherPriorityTaskWoken = pdFALSE;

    // Wake & invoke thread IMMEDIATELY.
    vTaskNotifyGiveFromISR(TaskHandle_t(ctrlLoopTaskHandle), &xHigherPriorityTaskWoken);
    portYIELD_FROM_ISR(xHigherPriorityTaskWoken);
}


/* Default Entry -------------------------------------------------------*/
void Main(void)
{
    // Init all communication staff, include USB-CDC/VCP/UART/CAN etc.
    InitCommunication();

    // Init & Run User Threads.
    const osThreadAttr_t controlLoopTask_attributes = {
        .name = "ControlLoopTask",
        .stack_size = 4096,
        .priority = (osPriority_t) osPriorityRealtime, // robot control thread is critical, should be the highest
    };
    ctrlLoopTaskHandle = osThreadNew(ThreadCtrlLoop, nullptr, &controlLoopTask_attributes);

    const osThreadAttr_t oledTask_attributes = {
        .name = "OledTask",
        .stack_size = 4096,
        .priority = (osPriority_t) osPriorityNormal,   // should >= Normal
    };
    oledTaskHandle = osThreadNew(ThreadOledUpdate, nullptr, &oledTask_attributes);

    const osThreadAttr_t peripheralTask_attributes = {
        .name = "peripheralTask",
        .stack_size = 512,
        .priority = (osPriority_t) osPriorityNormal,
    };
    peripheralTaskHandle = osThreadNew(ThreadGpioUpdate, nullptr, &peripheralTask_attributes);


    // Start Timer Callbacks.
    timerCtrlLoop.SetCallback(OnTimerCallback);
    timerCtrlLoop.Start();
}


extern "C"
void HAL_SPI_TxCpltCallback(SPI_HandleTypeDef* hspi)
{
    rgb.isRgbTxBusy = false;
}

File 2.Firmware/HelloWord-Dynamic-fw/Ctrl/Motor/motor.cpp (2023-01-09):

#include "motor.h"
#include "st_hardware.h"
#include <cmath>


bool Motor::Init(float _zeroElectricOffset, EncoderBase::Direction _encoderDir)
{
    if (encoder) encoder->Init();
    if (driver) driver->Init();
    if (currentSense) currentSense->Init();

    if (!currentSense && ASSERT(phaseResistance))
    {
        float limit = config.currentLimit * phaseResistance;
        config.voltageLimit = limit < config.voltageLimit ? limit : config.voltageLimit;
    }

    if (config.voltageLimit > driver->voltagePowerSupply)
        config.voltageLimit = driver->voltagePowerSupply;

    if (config.voltageUsedForSensorAlign > config.voltageLimit)
        config.voltageUsedForSensorAlign = config.voltageLimit;

    if (currentSense)
    {
        config.pidCurrentQ.limit = config.voltageLimit;
        config.pidCurrentD.limit = config.voltageLimit;
        config.pidVelocity.limit = config.currentLimit;
    } else if (ASSERT(phaseResistance))
    {
        config.pidVelocity.limit = config.currentLimit;
    } else
    {
        config.pidVelocity.limit = config.voltageLimit;
    }
    config.pidAngle.limit = config.velocityLimit;

    return InitFOC(_zeroElectricOffset, _encoderDir);
}


void Motor::AttachEncoder(EncoderBase* _encoder)
{
    encoder = _encoder;
}


void Motor::AttachCurrentSense(CurrentSenseBase* _currentSense)
{
    currentSense = _currentSense;
}


void Motor::AttachDriver(DriverBase* _driver)
{
    driver = _driver;
}


void Motor::SetEnable(bool _enable)
{
    enabled = _enable;
}


float Motor::GetEstimateAngle()
{
    // If no sensor linked return previous value (for open-loop case)
    if (!encoder) return estimateAngle;
    state.rawAngle = (float) (encoder->countDirection) * encoder->GetFullAngle();
    state.estAngle = config.lpfAngle(state.rawAngle);

    return state.estAngle;
}


float Motor::GetEstimateVelocity()
{
    // If no sensor linked return previous value (for open-loop case)
    if (!encoder) return estimateVelocity;
    state.rawVelocity = (float) (encoder->countDirection) * encoder->GetVelocity();
    state.estVelocity = config.lpfVelocity(state.rawVelocity);

    return state.estVelocity;
}


float Motor::GetElectricalAngle()
{
    // If no sensor linked return previous value (for open-loop case)
    return encoder ? Normalize((float) (encoder->countDirection * polePairs)
                               * encoder->GetLapAngle() - zeroElectricAngleOffset)
                   : electricalAngle;
}


void Motor::Tick()
{
    CloseLoopControlTick();
    FocOutputTick();
}


bool Motor::InitFOC(float _zeroElectricOffset, EncoderBase::Direction _sensorDirection)
{
    // Absolute zero offset provided, no need to align
    if (ASSERT(_zeroElectricOffset))
    {
        zeroElectricAngleOffset = _zeroElectricOffset;
        encoder->countDirection = _sensorDirection;
    }

    if (encoder)
    {
        if (!AlignSensor()) return false;

        encoder->Update();
        estimateAngle = GetEstimateAngle();
    }

    return true;
}


bool Motor::AlignSensor()
{
    if (encoder->countDirection == EncoderBase::UNKNOWN)
    {
        SetPowerMotor(true);
        HAL_Delay(100);

        // Find natural direction
        for (int i = 0; i <= 500; i++)
        {
            float angle = _3PI_2 + _2PI * (float) i / 500.0f;
            SetPhaseVoltage(config.voltageUsedForSensorAlign, 0, angle);
            HAL_Delay(2);
        }

        encoder->Update();
        float midAngle = encoder->GetFullAngle();

        for (int i = 500; i >= 0; i--)
        {
            float angle = _3PI_2 + _2PI * (float) i / 500.0f;
            SetPhaseVoltage(config.voltageUsedForSensorAlign, 0, angle);
            HAL_Delay(2);
        }

        encoder->Update();
        float endAngle = encoder->GetFullAngle();

        SetPhaseVoltage(0, 0, 0);
        SetPowerMotor(false);
        HAL_Delay(200);

        // Determine the direction the sensor moved
        if (midAngle == endAngle)
        {
            error = FAILED_TO_NOTICE_MOVEMENT;
            return false;
        } else if (midAngle < endAngle)
        {
            encoder->countDirection = EncoderBase::Direction::CCW;
        } else
        {
            encoder->countDirection = EncoderBase::Direction::CW;
        }

        // Check pole pair number
        float deltaAngle = std::fabs(midAngle - endAngle);
        if (std::fabs(deltaAngle * (float) polePairs - _2PI) > 0.5f)
        {
            // 0.5f is arbitrary number, it can be tuned
            error = POLE_PAIR_MISMATCH;
            return false;
        }
    }

    // Align the electrical phases of the motor and sensor
    if (!ASSERT(zeroElectricAngleOffset))
    {
        SetPowerMotor(true);
        // Set angle -90(270 = 3PI/2) degrees
        SetPhaseVoltage(config.voltageUsedForSensorAlign, 0, _3PI_2);

        HAL_Delay(1000);
        encoder->Update();
        zeroElectricAngleOffset = 0; // Clear offset first
        zeroElectricAngleOffset = GetElectricalAngle();

        SetPhaseVoltage(0, 0, 0);
        SetPowerMotor(false);
        HAL_Delay(200);
    }

    return true;
}


void Motor::CloseLoopControlTick()
{
    // No need to read shaftAngle in open-loop mode
    if (config.controlMode != ControlMode_t::ANGLE_OPEN_LOOP &&
        config.controlMode != ControlMode_t::VELOCITY_OPEN_LOOP)
    {
        estimateAngle = GetEstimateAngle();
    }

    estimateVelocity = GetEstimateVelocity();

    if (!enabled) return;

    switch (config.controlMode)
    {
        case ControlMode_t::TORQUE:
            voltage.q = ASSERT(phaseResistance) ? target * phaseResistance : target;
            voltage.d = 0;
            setPointCurrent = voltage.q;
            break;
        case ControlMode_t::ANGLE:
            setPointAngle = target;
            setPointVelocity = config.pidAngle(setPointAngle - estimateAngle);
            setPointCurrent = config.pidVelocity(setPointVelocity - estimateVelocity);
            break;
        case ControlMode_t::VELOCITY:
            setPointVelocity = target;
            setPointCurrent = config.pidVelocity(setPointVelocity - estimateVelocity);
            break;
        case ControlMode_t::VELOCITY_OPEN_LOOP:
            setPointVelocity = target;
            voltage.q = VelocityOpenLoopTick(setPointVelocity);
            voltage.d = 0;
            break;
        case ControlMode_t::ANGLE_OPEN_LOOP:
            setPointAngle = target;
            voltage.q = AngleOpenLoopTick(setPointAngle);
            voltage.d = 0;
            break;
    }
}
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

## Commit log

2022-07-31 [Hw] Add schematic.
2022-07-31 [3D] Add model stl files.
    [05触摸条盖板.stl, 06触摸条盖板.stl, 06防滑脚垫.stl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]
2022-08-01 Add topology graphic of PCBs
2022-08-02 Update topology
    * Add missing E-Ink
    * Fix SPI wiring to Encoder, which should be bidirectional
2022-08-20 [Hw] Add PCB source files.
2022-08-31 [Fw] Fixed PageUp not triggered bug.
    [hw_keyboard.h]
2023-01-08 修复 AlignSensor 时电机 12V 未使能的问题
    [motor.cpp]

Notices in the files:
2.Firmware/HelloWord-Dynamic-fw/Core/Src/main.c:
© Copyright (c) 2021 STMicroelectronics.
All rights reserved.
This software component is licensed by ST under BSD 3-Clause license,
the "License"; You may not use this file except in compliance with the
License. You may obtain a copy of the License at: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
